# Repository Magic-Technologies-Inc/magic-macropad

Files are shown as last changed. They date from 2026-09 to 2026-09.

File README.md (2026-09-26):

# Magic Macropad

A thin, three-key macropad that plugs straight into your MacBook's side USB-C
port and sits flush along the chassis, plus the menu-bar app that turns each
key into tap, double-tap, triple-tap, and hold actions.

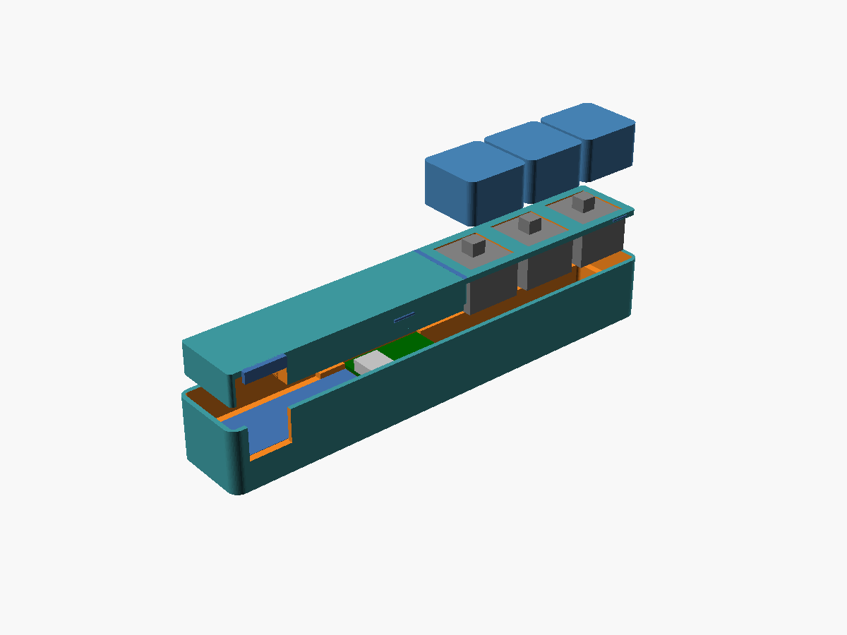
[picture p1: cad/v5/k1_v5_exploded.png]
Exploded view of the side-mount enclosure: tray, drop-in lid, three MX switches, and keycaps


> **Status: early prototype.** The firmware and app work, and the enclosures
> are tuned against real prints. Expect rough edges. The hardware's codename
> is **K1**, and you'll see it in file names and code.

## Features

- **Three keys, twelve bindings.** Each key does something different on tap,
  double-tap, triple-tap, and hold.
- **Per-app profiles.** Bindings follow the frontmost app and fall back to
  your Default profile.
- **Built-in actions:**
  - Open an app, URL, file, or folder
  - Keyboard shortcuts, with a recorder
  - Media: play/pause, previous/next, volume, mute
  - Paste a text snippet
  - System: app switcher (⌘Tab), mic mute, lock screen, display sleep, dark
    mode, region screenshot, Mission Control, keep-awake
  - AI: new Claude or ChatGPT chat, dictation
  - Shell scripts, with a preset library that includes Claude CLI helpers
    like "Improve Writing" for whatever's on the clipboard
- **No drivers.** The device is a vendor-defined USB HID device, so macOS
  needs nothing installed. Gesture timing lives in the app, so you can tune
  it without reflashing.
- **Key-press light.** The board's RGB LED glows red, green, or blue while a
  key is held.

There's also one easter egg. Try pressing all three keys at once.

## How it works

    keys ──► RP2040 firmware ─── USB HID ───► Magic Macropad app
             debounce, down/up events          HIDService → GestureEngine
             8-byte reports + sequence byte      → ActionEngine (per-app profiles)

The firmware only reports debounced key down/up events. It uses a
vendor-defined HID interface (usage page `0xFF60`, 8-byte reports with a
sequence byte). The app does everything else: gesture detection, profiles, and
running actions. The full design is in
[`docs/superpowers/specs/`](docs/superpowers/specs/).

## Build one

You'll need an RP2040-Zero, three MX-style switches and keycaps, some thin
wire, a 3D printer, and a soldering iron. The side-mount version also needs a
90° USB-C adapter and a USB-C coupler; the desk version uses a normal cable.

**[The build guide](docs/build-guide.md)** walks through it step by step:

1. Choose a variant: side-mount or desk
2. Gather parts and tools
3. Print the enclosure
4. Flash the firmware
5. Install the app
6. Wire and test the switches, with a wiring diagram and a self-test
7. Assemble
8. Troubleshooting
9. Changing the enclosure, for other USB parts or printers

Prebuilt firmware is on the
[Releases page](https://github.com/Magic-Technologies-Inc/magic-macropad/releases),
so you only need the firmware toolchain if you change the firmware. No board
yet? You can still install the app (step 5). Its **Test keys** menu simulates
presses.

## Repository layout

- `cad/`: OpenSCAD enclosure, one folder per revision (`v5/` and `desk/v2/`
  are current)
- `firmware/`: Pico SDK and TinyUSB firmware for the RP2040-Zero
- `mac/`: the menu-bar app (SwiftUI). `MagicKeysCore/` holds the unit-tested
  core. The target and package still use the older "Magic Keys" name.
- `docs/build-guide.md`: the step-by-step build guide
- `docs/superpowers/`: design specs and implementation plans. They predate the
  Magic Macropad name, so they still say "K1" and "Magic Keys".

## Contributing

See [CONTRIBUTING.md](CONTRIBUTING.md).

## License

Magic Macropad (hardware designs, firmware, and app) is © 2026 Magic
Technologies Inc., licensed under
[CC BY-NC-SA 4.0](https://creativecommons.org/licenses/by-nc-sa/4.0/). The
full text is in [LICENSE](LICENSE).

In plain English (the license itself is what counts):

- ✅ You can build one, change it, and share your changes. Credit Magic and
  keep the same license.
- ❌ You can't sell devices, kits, printed parts, or the software, modified or
  not.
- **Additional permission:** beyond CC BY-NC-SA 4.0, Magic Technologies Inc.
  lets you use a Magic Macropad you built yourself, along with its firmware
  and app, for your work, including at a for-profit company. This covers use
  only. It doesn't allow selling, renting, or otherwise commercially
  distributing devices, kits, parts, design files, or software.

For commercial licensing, get in touch at [usemagic.io](https://usemagic.io).

Some bundled fonts, a sound, and two small firmware files are third-party and
keep their own licenses; see [THIRD_PARTY_NOTICES.md](THIRD_PARTY_NOTICES.md). The Magic name and logo aren't
licensed at all; see [TRADEMARKS.md](TRADEMARKS.md).

---

Made by [Magic](https://usemagic.io).

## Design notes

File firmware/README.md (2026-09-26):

# Magic Macropad firmware

Pico SDK firmware for the RP2040-Zero (Waveshare design), codename K1. It
enumerates as a vendor HID device and reports debounced key down/up events:
manufacturer "Magic", product "Magic Macropad", VID 0x1209, PID 0x0001, usage
page 0xFF60. There's no gesture logic on the device. The protocol is in
`main/protocol.h`.

PID `0x0001` is the pid.codes shared *test* PID, a placeholder until the
project has its own.

Building a whole pad? Start with the [build guide](../docs/build-guide.md),
which also covers installing the toolchain. Prebuilt `.uf2` files are attached
to the GitHub releases.

## Build

    export PICO_SDK_PATH=~/pico-sdk        # Pico SDK 2.x with the tinyusb submodule
    export PICO_TOOLCHAIN_PATH=/path/to/arm-gnu-toolchain   # Arm GNU Toolchain 14.x (arm-none-eabi)
    cmake -B build -G Ninja -DCMAKE_BUILD_TYPE=Release
    ninja -C build

Produces `build/k1_firmware.uf2`. On macOS, use Arm's official toolchain
download. Homebrew's `arm-none-eabi-gcc` formula ships without newlib and
fails on `nosys.specs`.

## Flash

Hold BOOT while plugging the board in, then drag the UF2 onto the mounted
`RPI-RP2` volume, or run `picotool load -f build/k1_firmware.uf2`.

## Tests

- Host unit tests (no hardware):
  `cc -I main tests/host/test_debounce.c main/debounce.c -o /tmp/test_debounce && /tmp/test_debounce`
  and `cc -I main tests/host/test_keysync.c main/keysync.c -o /tmp/test_keysync && /tmp/test_keysync`
- Hardware-in-loop: `tools/smoke_test.py` (see its docstring)

Key GPIOs are defined in `main/keys.c` (`K1_KEY_GPIOS`): GPIO 12, 11, and 10
for keys 0, 1, and 2 (the app's Key 1–3). They're active-low (key to GND) with
internal pull-ups. Debug logs go out UART0 on GPIO 0/1 at 115200; wiring it is
optional.

While the host isn't listening (bus suspended, not yet mounted), key edges
are dropped rather than replayed later as live presses; when it's back, any
key whose state changed meanwhile is reported once (`main/keysync.c`).

The onboard WS2812 (GPIO 16) shows a dim per-key color while a key is held
(red/green/blue for keys 0/1/2); see `main/led.c`.

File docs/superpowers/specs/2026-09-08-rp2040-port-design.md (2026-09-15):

# K1 Firmware RP2040 Port — Design

**Date:** 2026-09-08
**Status:** Approved (replaces the ESP32-S3 target entirely)

## Decision

K1 firmware moves from the Seeed XIAO ESP32-S3 (ESP-IDF 5.x + `esp_tinyusb`)
to the **RP2040-Zero** (Waveshare design; hiBCTR clones on hand), built with
the **Raspberry Pi Pico SDK** and its bundled TinyUSB. The RP2040 replaces the
ESP32-S3 — there is no dual-target support. K1 never needed WiFi/BLE, the
RP2040 is cheaper, and its native USB + TinyUSB support is first-class.

## What does not change

- **Wire protocol** (`main/protocol.h`): 8-byte vendor HID reports, usage page
  `0xFF60`, VID `0x1209` / PID `0x0001` (dev), `KEY_EVENT` / `INFO` /
  `GET_INFO` messages, sequence byte semantics. Byte-for-byte identical.
- **Mac app (Magic Keys)**: zero changes. It matches on VID/PID/usage page and
  parses the same reports.
- **Debounce** (`main/debounce.c/h`): pure logic, 5 samples @ 1 kHz = 5 ms.
  Carries over untouched, along with its host unit test
  (`tests/host/test_debounce.c`).
- **Smoke test** (`tools/smoke_test.py`): host-side `hidapi` script; VID/PID
  and protocol unchanged, so it runs as-is.
- **Firmware-stays-dumb rule**: only debounced down/up events with a sequence
  byte; all gesture logic remains in the app.

## What changes

### Architecture: FreeRTOS tasks → bare-metal superloop

ESP-IDF forced FreeRTOS (scan task + report task + queue). The Pico SDK is
bare-metal by default and TinyUSB's idiomatic use is a main loop calling
`tud_task()`. The port drops FreeRTOS:

- `main()` loop: `tud_task()` → `k1_keys_poll()` → `k1_usb_flush()`.
- **Key scanning**: `k1_keys_poll()` self-paces to 1 kHz using
  `time_us_64()`; on each 1 ms tick it samples the three GPIOs, runs the
  debouncer, and pushes state changes into a `pico/util/queue` (32 entries,
  drop-oldest-behavior preserved: on a full queue the new event is dropped and
  logged, same as the ESP build).
- **Reporting**: `k1_usb_flush()` mirrors the old report task — answer a
  pending `GET_INFO` first, then drain one key event per call when
  `tud_hid_ready()`. Seq still only advances on successful `tud_hid_report()`.

The loop iterates in microseconds, so 1 kHz sampling jitter is negligible
versus the 5-sample debounce window.

### Files

| File | Change |
|---|---|
| `CMakeLists.txt` | Pico SDK project (`pico_sdk_import.cmake`, `PICO_BOARD=waveshare_rp2040_zero`) |
| `pico_sdk_import.cmake` | New — standard SDK import shim |
| `main/k1_main.c` | `app_main` → `main()` with init + superloop |
| `main/keys.c/h` | ESP GPIO/task/queue → Pico GPIO + polled scan + `pico/util/queue` |
| `main/usb_hid.c/h` | Descriptors/callbacks unchanged; `esp_tinyusb` install → `tusb_init()`; report task → `k1_usb_flush()` |
| `main/tusb_config.h` | New — TinyUSB device config (previously hidden in `esp_tinyusb` + sdkconfig) |
| `sdkconfig*`, `dependencies.lock`, `main/idf_component.yml` | Deleted (ESP-IDF artifacts) |

### Pins (RP2040-Zero)

Keys on **GPIO 10 / 11 / 12** (changed 2026-09-15 for the enclosure wiring;
previously 0/1/2, and 26/27/28 before that), active-low to GND, internal
pull-ups. Defined in one array in `keys.c`. Debug logging via `printf` on
UART0 (GPIO 0/1, 115200), optional to wire.

### Build & flash

- Toolchain: CMake + Ninja + `arm-none-eabi-gcc` + Pico SDK (pinned 2.x with
  TinyUSB submodule).
- `cmake -B build && ninja -C build` → `k1_firmware.uf2`.
- Flash: hold BOOT, plug in, drag the UF2 onto the `RPI-RP2` volume (or
  `picotool load`). No serial flasher, no `idf.py`.

## Error handling

Same posture as the ESP build: best-effort delivery. Queue overflow drops the
newest event with a log line; reports only send when the host is polling; a
failed `tud_hid_report()` does not advance the sequence byte, so the app's gap
detection only fires on real USB loss.

## Testing

1. Host unit test for debounce (unchanged, run in CI fashion locally).
2. Build must produce a UF2.
3. Hardware-in-loop: flash an RP2040-Zero, run `tools/smoke_test.py`
   (enumeration, GET_INFO round-trip, key events with jumper wire).

## Out of scope

- Enclosure CAD update — v2 CAD models the XIAO footprint; the RP2040-Zero is
  ~18×23.5 mm with a different pad layout, so the board pocket needs rework in
  a separate CAD task.
- ~~The WS2812 RGB LED on the RP2040-Zero (GPIO 16)~~ — added 2026-09-08 as a
  key-press indicator: PIO-driven WS2812 shows a dim per-key color while a key
  is held (red/green/blue for keys 0/1/2, highest-index wins), off otherwise.
  Purely local feedback; nothing on the wire.
- OTA/DFU beyond the built-in BOOTSEL UF2 bootloader.

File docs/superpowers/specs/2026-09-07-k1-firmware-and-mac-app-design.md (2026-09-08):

# K1 Firmware & Magic Keys Mac App — Design

**Date:** 2026-09-07
**Status:** Approved

## Product summary

K1 ("Keys v1") is a thin **3-key** macro pad built on an ESP32-S3. It plugs into a
MacBook's side USB-C port and sits flush along the chassis edge. The device is
**app-required**: it emits raw key events over USB and does nothing on its own.
The companion Mac app, **Magic Keys**, detects gestures (tap / double-tap / hold)
and executes user-configured actions, with a Logitech-Options-style configuration
UI.

> Note: `cad/k1_v1.scad` still models 4 keys (`key_count = 4`); the confirmed spec
> is 3 keys. CAD update is out of scope for this spec.

## Repository layout

Single repo (`K1/`) so protocol changes in firmware and app land together:

- `cad/` — enclosure sources and renders
- `firmware/` — ESP-IDF project
- `mac/` — Magic Keys Xcode project
- `docs/` — specs and plans

## Firmware (ESP-IDF + TinyUSB)

- **Stack:** ESP-IDF 5.x with the `esp_tinyusb` component. The ESP32-S3's native
  USB peripheral enumerates as a single **vendor-defined HID** interface, usage
  page `0xFF60` (QMK raw-HID convention), fixed 8-byte reports, full speed.
- **Input:** 3 keys on GPIOs, scanned by a FreeRTOS task with 5 ms debounce.
- **Deliberately dumb:** firmware sends only `down`/`up` events. All gesture
  timing lives in the app so it can be tuned without reflashing.
- **USB IDs (dev):** VID `0x1209` (pid.codes) with a test PID until Magic has its
  own VID.

### Report protocol (8 bytes, little-endian)

Device → host:

| Byte | Field | Values |
|---|---|---|
| 0 | msg | `0x01` KEY_EVENT, `0x02` INFO |
| 1 | key | 0–2 (KEY_EVENT) |
| 2 | state | `0x00` up, `0x01` down (KEY_EVENT) |
| 3 | seq | wrapping counter; app detects dropped reports |
| 4–7  | payload | INFO: fw version major/minor, key count, 0  |

Host → device (output report, 8 bytes): byte 0 `0x10` GET_INFO → device replies
with INFO. This is the extension point for future LED/config messages.

## Magic Keys Mac app

SwiftUI menu-bar app (`MenuBarExtra`), macOS 14+. Four isolated units:

1. **HIDService** — wraps `IOHIDManager`: matches VID/PID, handles
   hotplug/reconnect, parses raw reports into typed `KeyEvent`s, sends GET_INFO
   on connect. The only unit that touches IOKit.
2. **GestureEngine** — pure logic, no I/O. Consumes `KeyEvent`s, emits `tap`,
   `doubleTap`, `hold` per key. Thresholds configurable (defaults: double-tap
   window 300 ms, hold 400 ms). Fully unit-testable with synthetic events.
3. **ActionEngine** — executes the action bound to (key, gesture). V1 actions:
   - Open app
   - Open URL
   - Keyboard shortcut injection (`CGEvent`; requests Accessibility permission
     only when first used)
   - Media control (play/pause, volume up/down, mute)
   - Run shell script
   Actions are a Codable `ActionConfig` enum with an exhaustive switch in
   ActionEngine — adding a later action (e.g. smart-home triggers via the Magic
   FastAPI server) is one new enum case plus one switch arm, and the compiler
   flags every site that must handle it. (Chosen over a `MagicAction` protocol
   because enums get Codable persistence for free.)
4. **ConfigStore** — Codable JSON at
   `~/Library/Application Support/MagicKeys/config.json`, observed by the UI.

### Configuration UI

Logitech-Options-style window: K1 render on the left (placeholder:
`cad/k1_v1_assembled.png`), click a key to select it; right panel shows three
gesture slots (tap / double-tap / hold), each with an action picker and its
parameters. Menu-bar icon reflects connection state. Launch-at-login via
`SMAppService`.

## Error handling

- Disconnect → grayed menu icon, in-flight gesture state reset; IOHIDManager
  auto-resumes on replug.
- Malformed or out-of-sequence reports are logged and dropped.
- Failed actions (script error, missing app) post a user notification; the
  engine never crashes on action failure.

## Testing

- **GestureEngine / ConfigStore:** unit tests with synthetic event streams —
  the bulk of the logic, no hardware needed.
- **HID path:** debug-menu "virtual K1" injects fake reports so the whole app
  runs without hardware.
- **Firmware:** hardware-in-loop smoke test — Python `hidapi` script asserting
  key-event delivery and the GET_INFO round trip.

## Out of scope (v1)

- CAD change from 4 → 3 keys
- LEDs, on-device config storage, OTA/DFU
- Smart-home actions (protocol hook exists via `MagicAction`)
- Windows/Linux hosts

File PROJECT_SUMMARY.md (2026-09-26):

# Magic Macropad (K1) Project Summary

**Last updated:** 2026-09-26

## What it is

Magic Macropad (codename K1, "Keys v1") is a Magic hardware product: a thin
**3-key** macro pad that plugs into a MacBook's side USB-C port and sits flush
along the chassis edge, running toward the front. There's also a desk variant
that takes a normal cable. It's built on an **RP2040** (RP2040-Zero board) and
is **app-required**. The device sends raw key events over USB and does nothing
without the companion **Magic Macropad** Mac app, which detects gestures and
runs the user's configured actions.

## Key decisions

| Decision | Choice |
|---|---|
| Key count | 3 (CAD, firmware, and app) |
| Device model | App-required; no standalone HID-keyboard fallback |
| Transport | Native USB, vendor-defined HID (usage page `0xFF60`), 8-byte reports |
| Firmware stack | Pico SDK 2.x + TinyUSB (was ESP-IDF/ESP32-S3; ported 2026-09-08) |
| Board | RP2040-Zero (Waveshare design, hiBCTR clones); keys on GPIO 12/11/10 |
| Gesture logic | Entirely in the Mac app (tap / double-tap / triple-tap / hold); firmware sends only down/up |
| Mac app | SwiftUI menu-bar app, macOS 15+, `IOHIDManager` |
| Config UI | Logitech Options-style: device render, click a key, assign actions per gesture; per-app profiles |
| Actions | Open app/URL/file, keyboard shortcut, media, paste text, system actions, AI (Claude/ChatGPT/dictation), shell script (with presets) |
| Dev USB IDs | VID `0x1209` (pid.codes) + test PID until Magic has its own VID |
| License | CC BY-NC-SA 4.0 (source-available, non-commercial) plus a permission to use self-built devices at work; Magic name and logo reserved |

## Repository layout

- `cad/`: OpenSCAD enclosure revisions `v0`–`v5` (side-mount) and
  `desk/v1`–`v2`, with STLs, renders, and Bambu Studio projects
- `firmware/`: Pico SDK + TinyUSB vendor-HID firmware
- `mac/`: the Magic Macropad app (XcodeGen, target `MagicKeys`) and the
  `MagicKeysCore` package
- `docs/superpowers/specs/`: design specs (historical names)

## Current status

- ✅ Architecture designed and spec approved:
  [docs/superpowers/specs/2026-09-07-k1-firmware-and-mac-app-design.md](docs/superpowers/specs/2026-09-07-k1-firmware-and-mac-app-design.md)
- ✅ Implementation plans (firmware + Mac app, in docs/superpowers/plans/)
- ✅ Firmware: vendor-HID device with debounced key events + GET_INFO, ported
  to RP2040-Zero / Pico SDK, plus per-key WS2812 press colors
  (spec: docs/superpowers/specs/2026-09-08-rp2040-port-design.md)
- ✅ Magic Macropad app: HID pipeline, gesture engine, action engine, per-app
  profiles, config UI, Test keys menu
- ✅ Hardware bring-up (2026-09-08): flashed to a real RP2040-Zero, enumerates
  as 0x1209:0x0001 (product string then "K1", now "Magic Macropad"), smoke
  test PASS (GET_INFO + all key events, gapless seq). Flash tip: a
  CircuitPython board can be kicked into BOOTSEL from the Mac via a 1200-baud
  touch on its /dev/cu.usbmodem* port
- ✅ Enclosure at 3 keys around the RP2040-Zero; fit tuned empirically against
  prints (v4 was the first confirmed fit; v5 raises the USB corridor to meet
  the port; desk v2 is unprinted)
- ✅ Prepared for public release (2026-09-26): renamed Magic Macropad,
  CC BY-NC-SA 4.0, commercial Advercase font purged from history
- ⬜ End-to-end: keys → Magic Macropad app gestures → actions
- ⬜ Dedicated USB PID (pid.codes needs an open-source license, so likely
  Raspberry Pi's RP2040 PID program)

## Explicitly out of scope for v1

On-device config, OTA/DFU, smart-home actions (would be a new `ActionConfig`
case), non-Mac hosts.

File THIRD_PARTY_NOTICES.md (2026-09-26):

# Third-party notices

Magic Macropad is licensed under [CC BY-NC-SA 4.0](LICENSE). The third-party
material below is **not** covered by that license. Each item keeps its own
license. The Magic name and logo aren't licensed at all; see
[TRADEMARKS.md](TRADEMARKS.md).

## Included in this repository

### Inter (UI text font)

- Files: `mac/MagicKeys/Resources/Inter-{Regular,Medium,SemiBold,Bold}.ttf`
- Copyright 2016 The Inter Project Authors (<https://github.com/rsms/inter>)
- License: SIL Open Font License 1.1. The full text ships next to the fonts in
  [`mac/MagicKeys/Resources/Inter-OFL.txt`](mac/MagicKeys/Resources/Inter-OFL.txt)
  and is bundled into the app.

### Easter-egg sound

- File: `mac/MagicKeys/Resources/fart.mp3`
- Source: Pixabay sound effect #6139 ("wet fart", uploaded by
  freesound_community)
- License: [Pixabay Content License](https://pixabay.com/service/license-summary/).
  It's bundled as an app resource. Don't redistribute it on its own.

### Raspberry Pi code (BSD-3-Clause)

- `firmware/main/ws2812.pio`: the WS2812 driver from
  [pico-examples](https://github.com/raspberrypi/pico-examples), trimmed
- `firmware/pico_sdk_import.cmake`: copied from the
  [Pico SDK](https://github.com/raspberrypi/pico-sdk)

Both are under this license:

```text
Copyright 2020 (c) 2020 Raspberry Pi (Trading) Ltd.

Redistribution and use in source and binary forms, with or without modification, are permitted provided that the
following conditions are met:

1. Redistributions of source code must retain the above copyright notice, this list of conditions and the following
   disclaimer.

2. Redistributions in binary form must reproduce the above copyright notice, this list of conditions and the following
   disclaimer in the documentation and/or other materials provided with the distribution.

3. Neither the name of the copyright holder nor the names of its contributors may be used to endorse or promote products
   derived from this software without specific prior written permission.

THIS SOFTWARE IS PROVIDED BY THE COPYRIGHT HOLDERS AND CONTRIBUTORS "AS IS" AND ANY EXPRESS OR IMPLIED WARRANTIES,
INCLUDING, BUT NOT LIMITED TO, THE IMPLIED WARRANTIES OF MERCHANTABILITY AND FITNESS FOR A PARTICULAR PURPOSE ARE
DISCLAIMED. IN NO EVENT SHALL THE COPYRIGHT HOLDER OR CONTRIBUTORS BE LIABLE FOR ANY DIRECT, INDIRECT, INCIDENTAL,
SPECIAL, EXEMPLARY, OR CONSEQUENTIAL DAMAGES (INCLUDING, BUT NOT LIMITED TO, PROCUREMENT OF SUBSTITUTE GOODS OR
SERVICES; LOSS OF USE, DATA, OR PROFITS; OR BUSINESS INTERRUPTION) HOWEVER CAUSED AND ON ANY THEORY OF LIABILITY,
WHETHER IN CONTRACT, STRICT LIABILITY, OR TORT (INCLUDING NEGLIGENCE OR OTHERWISE) ARISING IN ANY WAY OUT OF THE USE OF
THIS SOFTWARE, EVEN IF ADVISED OF THE POSSIBILITY OF SUCH DAMAGE.
```

## Not included

### Advercase (display font)

Magic's brand display face, © Indieground Design. It's commercially licensed
and can't be redistributed, so it isn't in this repo or its history. The app
falls back to the system font without it. Official builds add licensed copies
locally; the paths are gitignored.

## Fetched at build time (not vendored, apart from the two files above)

- [Raspberry Pi Pico SDK](https://github.com/raspberrypi/pico-sdk): BSD-3-Clause
- [TinyUSB](https://github.com/hathach/tinyusb), pulled in by the Pico SDK: MIT

Firmware binaries you build (`.uf2`) contain code from both. If you distribute
binaries, include their copyright notices.

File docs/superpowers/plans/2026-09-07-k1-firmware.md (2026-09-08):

# K1 Firmware Implementation Plan

> **For agentic workers:** REQUIRED SUB-SKILL: Use superpowers:subagent-driven-development (recommended) or superpowers:executing-plans to implement this plan task-by-task. Steps use checkbox (`- [ ]`) syntax for tracking.

**Goal:** ESP32-S3 firmware that enumerates as a vendor-defined USB HID device and reports debounced key down/up events for the 3 keys, answering GET_INFO requests.

**Architecture:** ESP-IDF 5.x + the `esp_tinyusb` component. A scan task samples 3 GPIOs every 1 ms through a host-testable debounce module and pushes events to a FreeRTOS queue; a USB task drains the queue into 8-byte HID input reports. Host→device output reports handle GET_INFO. No gesture logic on-device (see `CLAUDE.md`).

**Tech Stack:** ESP-IDF 5.x, TinyUSB via `espressif/esp_tinyusb`, FreeRTOS, plain `cc` for host unit tests, Python `hidapi` for the hardware-in-loop smoke test.

**Prerequisite:** ESP-IDF installed and exported (`. $IDF_PATH/export.sh` or `idf.py --version` works). All `idf.py` commands run from `firmware/`.

**Protocol (from spec — single source of truth is `main/protocol.h` once created):**
8-byte reports. Device→host: byte0 msg (`0x01` KEY_EVENT, `0x02` INFO), byte1 key (0–2), byte2 state (0 up / 1 down), byte3 wrapping seq, bytes4–7 payload (INFO: fw major, fw minor, key count, 0). Host→device: byte0 `0x10` GET_INFO. USB IDs: VID `0x1209`, PID `0x0001` (pid.codes test PID). HID usage page `0xFF60`, usage `0x61`.

---

### Task 1: ESP-IDF project scaffold

**Files:**
- Create: `firmware/CMakeLists.txt`
- Create: `firmware/sdkconfig.defaults`
- Create: `firmware/main/CMakeLists.txt`
- Create: `firmware/main/idf_component.yml`
- Create: `firmware/main/k1_main.c`

- [ ] **Step 1: Write the project files**

`firmware/CMakeLists.txt`:

```cmake
cmake_minimum_required(VERSION 3.16)
include($ENV{IDF_PATH}/tools/cmake/project.cmake)
project(k1_firmware)
```

`firmware/sdkconfig.defaults`:

```
CONFIG_IDF_TARGET="esp32s3"
CONFIG_TINYUSB_HID_COUNT=1
```

`firmware/main/CMakeLists.txt`:

```cmake
idf_component_register(
    SRCS "k1_main.c"
    INCLUDE_DIRS "."
)
```

`firmware/main/idf_component.yml`:

```yaml
dependencies:
  espressif/esp_tinyusb: "^1"
  idf: ">=5.0"
```

`firmware/main/k1_main.c`:

```c
#include "esp_log.h"

static const char *TAG = "k1";

void app_main(void)
{
    ESP_LOGI(TAG, "K1 firmware boot");
}
```

- [ ] **Step 2: Verify it builds**

Run: `cd firmware && idf.py set-target esp32s3 && idf.py build`
Expected: `Project build complete.` (first run downloads `esp_tinyusb` into `managed_components/`).

- [ ] **Step 3: Commit**

```bash
git add firmware/CMakeLists.txt firmware/sdkconfig.defaults firmware/main/
git commit -m "firmware: ESP-IDF project scaffold for ESP32-S3"
```

---

### Task 2: Protocol header

**Files:**
- Create: `firmware/main/protocol.h`

- [ ] **Step 1: Write the header**

```c
// protocol.h — K1 <-> Magic Keys wire protocol. 8-byte HID reports.
// This file is the single source of truth; the Mac app's Protocol.swift mirrors it.
#pragma once
#include <stdint.h>

#define K1_KEY_COUNT        3
#define K1_REPORT_SIZE      8

#define K1_USB_VID          0x1209  // pid.codes (dev)
#define K1_USB_PID          0x0001  // pid.codes test PID (dev)
#define K1_HID_USAGE_PAGE   0xFF60
#define K1_HID_USAGE        0x61

#define K1_FW_VERSION_MAJOR 0
#define K1_FW_VERSION_MINOR 1

// Device -> host, byte 0
#define K1_MSG_KEY_EVENT    0x01
#define K1_MSG_INFO         0x02
// Host -> device, byte 0
#define K1_MSG_GET_INFO     0x10

// KEY_EVENT byte 2
#define K1_KEY_UP           0x00
#define K1_KEY_DOWN         0x01

typedef struct {
    uint8_t key;    // 0..K1_KEY_COUNT-1
    uint8_t state;  // K1_KEY_UP / K1_KEY_DOWN
} k1_key_event_t;
```

- [ ] **Step 2: Verify it still builds**

Run: `cd firmware && idf.py build`
Expected: `Project build complete.`

- [ ] **Step 3: Commit**

```bash
git add firmware/main/protocol.h
git commit -m "firmware: protocol constants for 8-byte HID reports"
```

---

### Task 3: Debounce module (host-tested, TDD)

The debounce logic is pure C with no ESP-IDF includes so it compiles on the Mac with `cc`.
Contract: sample raw key level every 1 ms; a state change is reported only after
`K1_DEBOUNCE_SAMPLES` (5) consecutive identical samples that differ from the stable state.

**Files:**
- Create: `firmware/main/debounce.h`
- Create: `firmware/main/debounce.c`
- Create: `firmware/tests/host/test_debounce.c`

- [ ] **Step 1: Write the header and the failing test**

`firmware/main/debounce.h`:

```c
#pragma once
#include <stdbool.h>
#include <stdint.h>

#define K1_DEBOUNCE_SAMPLES 5  // at 1 ms/sample => 5 ms debounce

typedef struct {
    bool stable;     // debounced state (true = pressed)
    bool candidate;  // last raw sample
    uint8_t count;   // consecutive samples matching candidate
} k1_debounce_t;

void k1_debounce_init(k1_debounce_t *d, bool initial);
// Feed one raw sample. Returns true iff the stable state just changed
// (read the new state from d->stable).
bool k1_debounce_update(k1_debounce_t *d, bool raw);
```

`firmware/tests/host/test_debounce.c`:

```c
#include <assert.h>
#include <stdio.h>
#include "debounce.h"

static void test_stays_idle_without_input(void) {
    k1_debounce_t d;
    k1_debounce_init(&d, false);
    for (int i = 0; i < 100; i++) assert(!k1_debounce_update(&d, false));
    assert(d.stable == false);
}

static void test_clean_press_fires_after_5_samples(void) {
    k1_debounce_t d;
    k1_debounce_init(&d, false);
    for (int i = 0; i < K1_DEBOUNCE_SAMPLES - 1; i++)
        assert(!k1_debounce_update(&d, true));
    assert(k1_debounce_update(&d, true));   // 5th sample flips it
    assert(d.stable == true);
    assert(!k1_debounce_update(&d, true));  // no repeat events while held
}

static void test_bounce_is_ignored(void) {
    k1_debounce_t d;
    k1_debounce_init(&d, false);
    // 3 pressed samples, then a bounce back to released, resets the counter
    assert(!k1_debounce_update(&d, true));
    assert(!k1_debounce_update(&d, true));
    assert(!k1_debounce_update(&d, true));
    assert(!k1_debounce_update(&d, false));
    assert(d.stable == false);
    // now a clean press still needs 5 consecutive samples
    for (int i = 0; i < K1_DEBOUNCE_SAMPLES - 1; i++)
        assert(!k1_debounce_update(&d, true));
    assert(k1_debounce_update(&d, true));
}

static void test_release_debounces_too(void) {
    k1_debounce_t d;
    k1_debounce_init(&d, true);
    for (int i = 0; i < K1_DEBOUNCE_SAMPLES - 1; i++)
        assert(!k1_debounce_update(&d, false));
    assert(k1_debounce_update(&d, false));
    assert(d.stable == false);
}

int main(void) {
    test_stays_idle_without_input();
    test_clean_press_fires_after_5_samples();
    test_bounce_is_ignored();
    test_release_debounces_too();
    printf("debounce: all tests passed\n");
    return 0;
}
```

- [ ] **Step 2: Run the test to verify it fails**

Run: `cd firmware && cc -I main tests/host/test_debounce.c main/debounce.c -o /tmp/test_debounce && /tmp/test_debounce`
Expected: FAIL — `main/debounce.c: No such file or directory` (not written yet).

- [ ] **Step 3: Write the implementation**

`firmware/main/debounce.c`:

```c
#include "debounce.h"

void k1_debounce_init(k1_debounce_t *d, bool initial)
{
    d->stable = initial;
    d->candidate = initial;
    d->count = 0;
}

bool k1_debounce_update(k1_debounce_t *d, bool raw)
{
    if (raw != d->candidate) {
        d->candidate = raw;
        d->count = 1;
        return false;
    }
    if (d->candidate == d->stable) {
        d->count = 0;
        return false;
    }
    if (++d->count >= K1_DEBOUNCE_SAMPLES) {
        d->stable = d->candidate;
        d->count = 0;
        return true;
    }
    return false;
}
```

- [ ] **Step 4: Run the test to verify it passes**

Run: `cd firmware && cc -I main tests/host/test_debounce.c main/debounce.c -o /tmp/test_debounce && /tmp/test_debounce`
Expected: `debounce: all tests passed`

- [ ] **Step 5: Add debounce.c to the ESP build and verify**

In `firmware/main/CMakeLists.txt`, change the SRCS line:

```cmake
idf_component_register(
    SRCS "k1_main.c" "debounce.c"
    INCLUDE_DIRS "."
)
```

Run: `cd firmware && idf.py build`
Expected: `Project build complete.`

- [ ] **Step 6: Commit**

```bash
git add firmware/main/debounce.h firmware/main/debounce.c firmware/tests/host/test_debounce.c firmware/main/CMakeLists.txt
git commit -m "firmware: host-tested debounce module (5 ms, 1 ms sampling)"
```

---

### Task 4: Key scan task

**Files:**
- Create: `firmware/main/keys.h`
- Create: `firmware/main/keys.c`
- Modify: `firmware/main/CMakeLists.txt`
- Modify: `firmware/main/k1_main.c`

Keys are active-low on GPIO 1, 2, 3 with internal pull-ups (breadboard wiring as of
2026-09-07; `K1_KEY_GPIOS` in keys.c is the only place pins appear). Wire each key
between its GPIO and GND. Note: GPIO 3 is an ESP32-S3 strapping pin (JTAG source
selection) — harmless with default eFuses, but avoid holding key 3 down during reset.

- [ ] **Step 1: Write keys.h**

```c
#pragma once
#include "freertos/FreeRTOS.h"
#include "freertos/queue.h"

// Starts the 1 kHz scan task. Debounced key events are posted to the
// returned queue as k1_key_event_t (see protocol.h).
QueueHandle_t k1_keys_start(void);
```

- [ ] **Step 2: Write keys.c**

```c
#include "keys.h"
#include "protocol.h"
#include "debounce.h"
#include "driver/gpio.h"
#include "esp_log.h"
#include "freertos/task.h"

static const char *TAG = "k1_keys";

// Active-low keys, wired key -> GND on the breadboard.
static const gpio_num_t K1_KEY_GPIOS[K1_KEY_COUNT] = {
    GPIO_NUM_1, GPIO_NUM_2, GPIO_NUM_3,
};

static QueueHandle_t s_event_queue;

static void scan_task(void *arg)
{
    k1_debounce_t db[K1_KEY_COUNT];
    for (int i = 0; i < K1_KEY_COUNT; i++)
        k1_debounce_init(&db[i], false);

    TickType_t last_wake = xTaskGetTickCount();
    for (;;) {
        for (int i = 0; i < K1_KEY_COUNT; i++) {
            bool pressed = gpio_get_level(K1_KEY_GPIOS[i]) == 0; // active low
            if (k1_debounce_update(&db[i], pressed)) {
                k1_key_event_t ev = {
                    .key = (uint8_t)i,
                    .state = db[i].stable ? K1_KEY_DOWN : K1_KEY_UP,
                };
                if (xQueueSend(s_event_queue, &ev, 0) != pdTRUE)
                    ESP_LOGW(TAG, "event queue full, dropped key %d", i);
            }
        }
        vTaskDelayUntil(&last_wake, pdMS_TO_TICKS(1));
    }
}

QueueHandle_t k1_keys_start(void)
{
    gpio_config_t cfg = {
        .mode = GPIO_MODE_INPUT,
        .pull_up_en = GPIO_PULLUP_ENABLE,
    };
    for (int i = 0; i < K1_KEY_COUNT; i++) {
        cfg.pin_bit_mask = 1ULL << K1_KEY_GPIOS[i];
        ESP_ERROR_CHECK(gpio_config(&cfg));
    }
    s_event_queue = xQueueCreate(32, sizeof(k1_key_event_t));
    configASSERT(s_event_queue);
    xTaskCreate(scan_task, "k1_scan", 3072, NULL, 10, NULL);
    return s_event_queue;
}
```

- [ ] **Step 3: Wire into main and the build**

`firmware/main/CMakeLists.txt` SRCS becomes:

```cmake
idf_component_register(
    SRCS "k1_main.c" "debounce.c" "keys.c"
    INCLUDE_DIRS "."
)
```

`firmware/main/k1_main.c` becomes:

```c
#include "esp_log.h"
#include "keys.h"
#include "protocol.h"
#include "freertos/FreeRTOS.h"
#include "freertos/queue.h"

static const char *TAG = "k1";

void app_main(void)
{
    ESP_LOGI(TAG, "K1 firmware boot, fw %d.%d",
             K1_FW_VERSION_MAJOR, K1_FW_VERSION_MINOR);
    QueueHandle_t q = k1_keys_start();

    // Temporary: log events until USB lands (replaced in Task 5).
    k1_key_event_t ev;
    for (;;) {
        if (xQueueReceive(q, &ev, portMAX_DELAY) == pdTRUE)
            ESP_LOGI(TAG, "key %d %s", ev.key,
                     ev.state == K1_KEY_DOWN ? "down" : "up");
    }
}
```

- [ ] **Step 4: Build (and flash if hardware is connected)**

Run: `cd firmware && idf.py build`
Expected: `Project build complete.`

If a board is connected: `idf.py flash monitor` — pressing keys (or grounding GPIO 1/2/3) logs `key N down` / `key N up`, one pair per press, no bounce storms. Ctrl+] exits monitor.

- [ ] **Step 5: Commit**

```bash
git add firmware/main/keys.h firmware/main/keys.c firmware/main/k1_main.c firmware/main/CMakeLists.txt
git commit -m "firmware: 1 kHz debounced key scan task on GPIO 4/5/6"
```

---

### Task 5: USB vendor HID device

**Files:**
- Create: `firmware/main/usb_hid.h`
- Create: `firmware/main/usb_hid.c`
- Modify: `firmware/main/CMakeLists.txt`
- Modify: `firmware/main/k1_main.c`

- [ ] **Step 1: Write usb_hid.h**

```c
#pragma once
#include "freertos/FreeRTOS.h"
#include "freertos/queue.h"

// Installs TinyUSB and starts the report task, which drains key events
// from `key_queue` into HID input reports (see protocol.h).
void k1_usb_start(QueueHandle_t key_queue);
```

- [ ] **Step 2: Write usb_hid.c**

```c
#include "usb_hid.h"
#include "protocol.h"
#include "esp_log.h"
#include "freertos/task.h"
#include "tinyusb.h"
#include "class/hid/hid_device.h"
#include <string.h>

static const char *TAG = "k1_usb";

// ---- Descriptors -----------------------------------------------------------

// Vendor-defined raw HID: 8-byte input + 8-byte output report, no report ID.
static const uint8_t k1_report_descriptor[] = {
    0x06, (K1_HID_USAGE_PAGE & 0xFF), (K1_HID_USAGE_PAGE >> 8), // Usage Page (0xFF60)
    0x09, K1_HID_USAGE,             // Usage (0x61)
    0xA1, 0x01,                     // Collection (Application)
    0x09, 0x62,                     //   Usage (vendor, input)
    0x15, 0x00,                     //   Logical Min 0
    0x26, 0xFF, 0x00,               //   Logical Max 255
    0x75, 0x08,                     //   Report Size 8 bits
    0x95, K1_REPORT_SIZE,           //   Report Count 8
    0x81, 0x02,                     //   Input (Data,Var,Abs)
    0x09, 0x63,                     //   Usage (vendor, output)
    0x15, 0x00,
    0x26, 0xFF, 0x00,
    0x75, 0x08,
    0x95, K1_REPORT_SIZE,
    0x91, 0x02,                     //   Output (Data,Var,Abs)
    0xC0                            // End Collection
};

static const tusb_desc_device_t k1_device_descriptor = {
    .bLength = sizeof(tusb_desc_device_t),
    .bDescriptorType = TUSB_DESC_DEVICE,
    .bcdUSB = 0x0200,
    .bDeviceClass = 0x00,
    .bDeviceSubClass = 0x00,
    .bDeviceProtocol = 0x00,
    .bMaxPacketSize0 = CFG_TUD_ENDPOINT0_SIZE,
    .idVendor = K1_USB_VID,
    .idProduct = K1_USB_PID,
    .bcdDevice = 0x0001,
    .iManufacturer = 1,
    .iProduct = 2,
    .iSerialNumber = 3,
    .bNumConfigurations = 1,
};

static const char *k1_string_descriptor[] = {
    (const char[]){0x09, 0x04},  // 0: English (US)
    "Magic",                     // 1: manufacturer
    "K1",                        // 2: product
    "K1-DEV-0001",               // 3: serial
};

enum { ITF_NUM_HID = 0, ITF_NUM_TOTAL };
#define K1_CONFIG_DESC_LEN (TUD_CONFIG_DESC_LEN + TUD_HID_INOUT_DESC_LEN)

static const uint8_t k1_configuration_descriptor[] = {
    TUD_CONFIG_DESCRIPTOR(1, ITF_NUM_TOTAL, 0, K1_CONFIG_DESC_LEN,
                          TUSB_DESC_CONFIG_ATT_REMOTE_WAKEUP, 100),
    TUD_HID_INOUT_DESCRIPTOR(ITF_NUM_HID, 0, HID_ITF_PROTOCOL_NONE,
                             sizeof(k1_report_descriptor),
                             0x01 /* EP OUT */, 0x81 /* EP IN */,
                             K1_REPORT_SIZE, 5 /* poll ms */),
};

// ---- TinyUSB HID callbacks -------------------------------------------------

static uint8_t s_seq;
static volatile bool s_info_requested;

uint8_t const *tud_hid_descriptor_report_cb(uint8_t instance)
{
    (void)instance;
    return k1_report_descriptor;
}

uint16_t tud_hid_get_report_cb(uint8_t instance, uint8_t report_id,
                               hid_report_type_t report_type,
                               uint8_t *buffer, uint16_t reqlen)
{
    (void)instance; (void)report_id; (void)report_type; (void)buffer; (void)reqlen;
    return 0;
}

void tud_hid_set_report_cb(uint8_t instance, uint8_t report_id,
                           hid_report_type_t report_type,
                           uint8_t const *buffer, uint16_t bufsize)
{
    (void)instance; (void)report_id; (void)report_type;
    if (bufsize >= 1 && buffer[0] == K1_MSG_GET_INFO)
        s_info_requested = true;  // answered from the report task, not this ISR-ish context
}

// ---- Report task -----------------------------------------------------------

static void send_report(uint8_t msg, uint8_t b1, uint8_t b2,
                        uint8_t p0, uint8_t p1, uint8_t p2, uint8_t p3)
{
    uint8_t report[K1_REPORT_SIZE] = {msg, b1, b2, s_seq++, p0, p1, p2, p3};
    if (!tud_hid_report(0, report, sizeof(report)))
        ESP_LOGW(TAG, "report dropped (host not ready)");
}

static void report_task(void *arg)
{
    QueueHandle_t key_queue = (QueueHandle_t)arg;
    k1_key_event_t ev;
    for (;;) {
        if (s_info_requested && tud_hid_ready()) {
            s_info_requested = false;
            send_report(K1_MSG_INFO, 0, 0,
                        K1_FW_VERSION_MAJOR, K1_FW_VERSION_MINOR,
                        K1_KEY_COUNT, 0);
        }
        if (xQueueReceive(key_queue, &ev, pdMS_TO_TICKS(10)) == pdTRUE) {
            while (!tud_hid_ready())
                vTaskDelay(pdMS_TO_TICKS(1));
            send_report(K1_MSG_KEY_EVENT, ev.key, ev.state, 0, 0, 0, 0);
        }
    }
}

void k1_usb_start(QueueHandle_t key_queue)
{
    const tinyusb_config_t tusb_cfg = {
        .device_descriptor = &k1_device_descriptor,
        .string_descriptor = k1_string_descriptor,
        .string_descriptor_count =
            sizeof(k1_string_descriptor) / sizeof(k1_string_descriptor[0]),
        .external_phy = false,
        .configuration_descriptor = k1_configuration_descriptor,
    };
    ESP_ERROR_CHECK(tinyusb_driver_install(&tusb_cfg));
    xTaskCreate(report_task, "k1_usb_report", 4096, key_queue, 9, NULL);
    ESP_LOGI(TAG, "USB HID started (VID %04x PID %04x)", K1_USB_VID, K1_USB_PID);
}
```

- [ ] **Step 3: Wire into main and the build**

`firmware/main/CMakeLists.txt` SRCS becomes:

```cmake
idf_component_register(
    SRCS "k1_main.c" "debounce.c" "keys.c" "usb_hid.c"
    INCLUDE_DIRS "."
)
```

`firmware/main/k1_main.c` becomes (log loop replaced by USB):

```c
#include "esp_log.h"
#include "keys.h"
#include "usb_hid.h"
#include "protocol.h"

static const char *TAG = "k1";

void app_main(void)
{
    ESP_LOGI(TAG, "K1 firmware boot, fw %d.%d",
             K1_FW_VERSION_MAJOR, K1_FW_VERSION_MINOR);
    k1_usb_start(k1_keys_start());
}
```

- [ ] **Step 4: Build**

Run: `cd firmware && idf.py build`
Expected: `Project build complete.` If `tinyusb.h` is not found, `managed_components/` wasn't resolved — run `idf.py reconfigure` first. If the esp_tinyusb API differs (e.g. no `string_descriptor_count` field on the installed version), match the struct fields to `managed_components/espressif__esp_tinyusb/include/tinyusb.h` rather than fighting the pin — the descriptor content stays the same.

- [ ] **Step 5: Flash and verify enumeration on the Mac**

Run: `cd firmware && idf.py flash`

Then on the Mac: `system_profiler SPUSBDataType | grep -A6 K1`
Expected: a `K1` device with `Vendor ID: 0x1209`, `Product ID: 0x0001`.

- [ ] **Step 6: Commit**

```bash
git add firmware/main/usb_hid.h firmware/main/usb_hid.c firmware/main/k1_main.c firmware/main/CMakeLists.txt
git commit -m "firmware: vendor HID device, key events + GET_INFO over 8-byte reports"
```

---

### Task 6: Hardware-in-loop smoke test

**Files:**
- Create: `firmware/tools/smoke_test.py`
- Create: `firmware/tools/requirements.txt`

- [ ] **Step 1: Write the tool files**

`firmware/tools/requirements.txt`:

```
hidapi>=0.14
```

`firmware/tools/smoke_test.py`:

```python
#!/usr/bin/env python3
"""K1 hardware-in-loop smoke test.

Verifies: device opens, GET_INFO round-trips, and key events arrive
with correct shape and sequence numbers. Run with the K1 plugged in:

    python3 -m venv .venv && .venv/bin/pip install -r requirements.txt
    .venv/bin/python smoke_test.py
"""
import sys
import time

import hid

VID, PID = 0x1209, 0x0001
MSG_KEY_EVENT, MSG_INFO, MSG_GET_INFO = 0x01, 0x02, 0x10
KEY_COUNT = 3

def fail(msg):
    print(f"FAIL: {msg}")
    sys.exit(1)

def main():
    try:
        dev = hid.device()
        dev.open(VID, PID)
    except OSError:
        fail(f"no HID device {VID:04x}:{PID:04x} — is the K1 plugged in?")
    dev.set_nonblocking(False)
    print(f"opened {dev.get_manufacturer_string()} {dev.get_product_string()}")

    # GET_INFO round trip. First byte 0x00 is the report ID (none).
    dev.write([0x00, MSG_GET_INFO] + [0] * 7)
    report = dev.read(8, timeout_ms=1000)
    if not report:
        fail("no INFO reply within 1 s")
    if report[0] != MSG_INFO:
        fail(f"expected INFO (0x02), got 0x{report[0]:02x}")
    major, minor, keys = report[4], report[5], report[6]
    if keys != KEY_COUNT:
        fail(f"device reports {keys} keys, expected {KEY_COUNT}")
    print(f"INFO ok: fw {major}.{minor}, {keys} keys")

    # Key events: one press+release per key, in order.
    print("press and release each key once, left to right (30 s timeout)...")
    deadline = time.time() + 30
    seen, last_seq = [], None
    while len(seen) < KEY_COUNT * 2 and time.time() < deadline:
        report = dev.read(8, timeout_ms=500)
        if not report:
            continue
        if report[0] != MSG_KEY_EVENT:
            continue
        key, state, seq = report[1], report[2], report[3]
        if key >= KEY_COUNT or state not in (0, 1):
            fail(f"malformed report: {report}")
        if last_seq is not None and seq != (last_seq + 1) % 256:
            fail(f"sequence gap: {last_seq} -> {seq}")
        last_seq = seq
        seen.append((key, state))
        print(f"  key {key} {'down' if state else 'up'} (seq {seq})")
    if len(seen) < KEY_COUNT * 2:
        fail(f"timed out; saw {len(seen)}/{KEY_COUNT * 2} events")

    print("PASS: smoke test complete")

if __name__ == "__main__":
    main()
```

- [ ] **Step 2: Run it against hardware**

Run (from `firmware/tools/`):

```bash
python3 -m venv .venv && .venv/bin/pip install -r requirements.txt && .venv/bin/python smoke_test.py
```

Expected: `INFO ok: fw 0.1, 3 keys`, six key-event lines while pressing, then `PASS: smoke test complete`. (Skip gracefully if no hardware is attached — the script exits with the "is the K1 plugged in?" failure.)

- [ ] **Step 3: Add `.venv` to gitignore and commit**

Append to `.gitignore`:

```
firmware/tools/.venv/
```

```bash
git add firmware/tools/smoke_test.py firmware/tools/requirements.txt .gitignore
git commit -m "firmware: hidapi hardware-in-loop smoke test"
```

---

### Task 7: Documentation touch-up

**Files:**
- Modify: `firmware/README.md`
- Modify: `PROJECT_SUMMARY.md`

- [ ] **Step 1: Replace firmware/README.md**

```markdown
# K1 Firmware

ESP-IDF 5.x firmware for the ESP32-S3. Enumerates as a vendor HID device
(VID 0x1209, PID 0x0001, usage page 0xFF60) and reports debounced key
down/up events. Protocol: `main/protocol.h`. No gesture logic on-device.

## Build & flash

    idf.py set-target esp32s3   # first time only
    idf.py build
    idf.py flash monitor

## Tests

- Host unit tests (no hardware):
  `cc -I main tests/host/test_debounce.c main/debounce.c -o /tmp/test_debounce && /tmp/test_debounce`
- Hardware-in-loop: `tools/smoke_test.py` (see its docstring)

Key GPIOs are defined in `main/keys.c` (`K1_KEY_GPIOS`) — GPIO 1/2/3, active-low
(key to GND), internal pull-ups.
```

- [ ] **Step 2: Update PROJECT_SUMMARY.md status**

In the Current status list, change the firmware lines to:

```markdown
- ✅ Implementation plan (firmware + Mac app, in `docs/superpowers/plans/`)
- ✅ Firmware: vendor-HID device with debounced key events + GET_INFO
- ✅ Hardware-in-loop smoke test (Python `hidapi`)
```

- [ ] **Step 3: Commit**

```bash
git add firmware/README.md PROJECT_SUMMARY.md
git commit -m "docs: firmware build/test instructions, status update"
```

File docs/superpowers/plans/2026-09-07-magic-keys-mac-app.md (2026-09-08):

# Magic Keys Mac App Implementation Plan

> **For agentic workers:** REQUIRED SUB-SKILL: Use superpowers:subagent-driven-development (recommended) or superpowers:executing-plans to implement this plan task-by-task. Steps use checkbox (`- [ ]`) syntax for tracking.

**Goal:** SwiftUI menu-bar app that receives K1 key events over vendor HID, detects tap / double-tap / hold gestures, and runs user-configured actions, with a Logitech-style per-key config window.

**Architecture:** All pure logic (protocol parsing, gesture engine, config models, config store) lives in a SwiftPM package `MagicKeysCore`, unit-tested with `swift test` — no Xcode project needed for TDD. The app target (generated by XcodeGen) adds the I/O shells: `HIDService` (IOHIDManager, the only unit touching IOKit), `GesturePipeline` (timers), `ActionEngine` (AppKit/CGEvent execution), and the SwiftUI UI. A DEBUG-only "virtual K1" menu injects fake key events so the whole app runs without hardware.

**Tech Stack:** Swift 5.9+, SwiftUI `MenuBarExtra`, macOS 14+, IOKit.hid, XcodeGen, XCTest.

**Prerequisites:** Xcode 15+ installed; `brew install xcodegen`. All commands run from `mac/` unless noted.

**Protocol (mirrors `firmware/main/protocol.h`):** 8-byte reports; device→host byte0 `0x01` KEY_EVENT (byte1 key 0–2, byte2 state 0 up/1 down, byte3 seq) or `0x02` INFO (bytes4–6 = fw major, fw minor, key count); host→device byte0 `0x10` GET_INFO. VID `0x1209`, PID `0x0001`.

---

### Task 1: MagicKeysCore package scaffold

**Files:**
- Create: `mac/MagicKeysCore/Package.swift`
- Create: `mac/MagicKeysCore/Sources/MagicKeysCore/Protocol.swift` (stub)
- Create: `mac/MagicKeysCore/Tests/MagicKeysCoreTests/ProtocolTests.swift` (stub)

- [ ] **Step 1: Write the package manifest and stubs**

`mac/MagicKeysCore/Package.swift`:

```swift
// swift-tools-version: 5.9
import PackageDescription

let package = Package(
    name: "MagicKeysCore",
    platforms: [.macOS(.v14)],
    products: [
        .library(name: "MagicKeysCore", targets: ["MagicKeysCore"]),
    ],
    targets: [
        .target(name: "MagicKeysCore"),
        .testTarget(name: "MagicKeysCoreTests", dependencies: ["MagicKeysCore"]),
    ]
)
```

`mac/MagicKeysCore/Sources/MagicKeysCore/Protocol.swift`:

```swift
public enum K1Protocol {}
```

`mac/MagicKeysCore/Tests/MagicKeysCoreTests/ProtocolTests.swift`:

```swift
import XCTest
@testable import MagicKeysCore

final class ProtocolTests: XCTestCase {}
```

- [ ] **Step 2: Verify the package builds and tests run**

Run: `cd mac/MagicKeysCore && swift test`
Expected: `Executed 0 tests, with 0 failures`.

- [ ] **Step 3: Commit**

```bash
git add mac/MagicKeysCore
git commit -m "mac: MagicKeysCore SwiftPM package scaffold"
```

---

### Task 2: Protocol parsing (TDD)

**Files:**
- Modify: `mac/MagicKeysCore/Sources/MagicKeysCore/Protocol.swift`
- Modify: `mac/MagicKeysCore/Tests/MagicKeysCoreTests/ProtocolTests.swift`

- [ ] **Step 1: Write the failing tests**

Replace `ProtocolTests.swift`:

```swift
import XCTest
@testable import MagicKeysCore

final class ProtocolTests: XCTestCase {
    func testParsesKeyDownEvent() {
        let msg = K1Protocol.parse([0x01, 2, 1, 42, 0, 0, 0, 0])
        XCTAssertEqual(msg, .keyEvent(KeyEvent(key: 2, isDown: true, seq: 42)))
    }

    func testParsesKeyUpEvent() {
        let msg = K1Protocol.parse([0x01, 0, 0, 255, 0, 0, 0, 0])
        XCTAssertEqual(msg, .keyEvent(KeyEvent(key: 0, isDown: false, seq: 255)))
    }

    func testParsesInfo() {
        let msg = K1Protocol.parse([0x02, 0, 0, 7, 0, 1, 3, 0])
        XCTAssertEqual(msg, .info(DeviceInfo(firmwareMajor: 0, firmwareMinor: 1, keyCount: 3)))
    }

    func testRejectsWrongLength() {
        XCTAssertNil(K1Protocol.parse([0x01, 0, 1]))
    }

    func testRejectsUnknownMessage() {
        XCTAssertNil(K1Protocol.parse([0x77, 0, 0, 0, 0, 0, 0, 0]))
    }

    func testRejectsOutOfRangeKey() {
        XCTAssertNil(K1Protocol.parse([0x01, 3, 1, 0, 0, 0, 0, 0]))
    }

    func testRejectsInvalidState() {
        XCTAssertNil(K1Protocol.parse([0x01, 1, 2, 0, 0, 0, 0, 0]))
    }

    func testGetInfoReportShape() {
        XCTAssertEqual(K1Protocol.getInfoReport, [0x10, 0, 0, 0, 0, 0, 0, 0])
    }
}
```

- [ ] **Step 2: Run tests to verify they fail**

Run: `cd mac/MagicKeysCore && swift test`
Expected: compile errors — `KeyEvent`, `DeviceInfo`, `parse` don't exist yet.

- [ ] **Step 3: Write the implementation**

Replace `Protocol.swift`:

```swift
import Foundation

public struct KeyEvent: Equatable, Sendable {
    public let key: Int
    public let isDown: Bool
    public let seq: UInt8

    public init(key: Int, isDown: Bool, seq: UInt8) {
        self.key = key
        self.isDown = isDown
        self.seq = seq
    }
}

public struct DeviceInfo: Equatable, Sendable {
    public let firmwareMajor: Int
    public let firmwareMinor: Int
    public let keyCount: Int

    public init(firmwareMajor: Int, firmwareMinor: Int, keyCount: Int) {
        self.firmwareMajor = firmwareMajor
        self.firmwareMinor = firmwareMinor
        self.keyCount = keyCount
    }
}

public enum K1Message: Equatable, Sendable {
    case keyEvent(KeyEvent)
    case info(DeviceInfo)
}

/// Mirrors firmware/main/protocol.h — keep in lockstep.
public enum K1Protocol {
    public static let vendorID = 0x1209
    public static let productID = 0x0001
    public static let usagePage = 0xFF60
    public static let reportSize = 8
    public static let keyCount = 3

    static let msgKeyEvent: UInt8 = 0x01
    static let msgInfo: UInt8 = 0x02
    static let msgGetInfo: UInt8 = 0x10

    public static var getInfoReport: [UInt8] {
        [msgGetInfo, 0, 0, 0, 0, 0, 0, 0]
    }

    public static func parse(_ report: [UInt8]) -> K1Message? {
        guard report.count == reportSize else { return nil }
        switch report[0] {
        case msgKeyEvent:
            let key = Int(report[1])
            guard key < keyCount, report[2] <= 1 else { return nil }
            return .keyEvent(KeyEvent(key: key, isDown: report[2] == 1, seq: report[3]))
        case msgInfo:
            return .info(DeviceInfo(firmwareMajor: Int(report[4]),
                                    firmwareMinor: Int(report[5]),
                                    keyCount: Int(report[6])))
        default:
            return nil
        }
    }
}
```

- [ ] **Step 4: Run tests to verify they pass**

Run: `cd mac/MagicKeysCore && swift test`
Expected: `Executed 8 tests, with 0 failures`.

- [ ] **Step 5: Commit**

```bash
git add mac/MagicKeysCore
git commit -m "mac: K1 report parsing with validation"
```

---

### Task 3: Action and config models (TDD)

**Files:**
- Create: `mac/MagicKeysCore/Sources/MagicKeysCore/Actions.swift`
- Create: `mac/MagicKeysCore/Tests/MagicKeysCoreTests/ActionsTests.swift`

- [ ] **Step 1: Write the failing tests**

`ActionsTests.swift`:

```swift
import XCTest
@testable import MagicKeysCore

final class ActionsTests: XCTestCase {
    func testActionConfigRoundTripsThroughJSON() throws {
        let actions: [ActionConfig] = [
            .openApp(bundleID: "com.apple.Music"),
            .openURL(urlString: "https://usemagic.io"),
            .keystroke(keyCode: 15, modifiers: [.command, .shift]),
            .media(command: .playPause),
            .shellScript(script: "echo hi"),
        ]
        let data = try JSONEncoder().encode(actions)
        let decoded = try JSONDecoder().decode([ActionConfig].self, from: data)
        XCTAssertEqual(decoded, actions)
    }

    func testDefaultConfigHasThreeEmptyBindings() {
        let config = K1Config.makeDefault()
        XCTAssertEqual(config.keys.count, 3)
        for binding in config.keys {
            XCTAssertNil(binding.tap)
            XCTAssertNil(binding.doubleTap)
            XCTAssertNil(binding.hold)
        }
    }

    func testBindingLookupByGesture() {
        var config = K1Config.makeDefault()
        config.keys[1].doubleTap = .media(command: .mute)
        XCTAssertEqual(config.action(for: .doubleTap(key: 1)), .media(command: .mute))
        XCTAssertNil(config.action(for: .tap(key: 1)))
        XCTAssertNil(config.action(for: .doubleTap(key: 0)))
        XCTAssertNil(config.action(for: .tap(key: 9)))  // out of range is nil, not a crash
    }
}
```

- [ ] **Step 2: Run tests to verify they fail**

Run: `cd mac/MagicKeysCore && swift test`
Expected: compile errors — `ActionConfig`, `K1Config`, `Gesture` don't exist yet. (`Gesture` is defined here; the engine that emits it comes in Task 4.)

- [ ] **Step 3: Write the implementation**

`Actions.swift`:

```swift
import Foundation

public enum Gesture: Equatable, Sendable {
    case tap(key: Int)
    case doubleTap(key: Int)
    case hold(key: Int)
}

public enum KeyModifier: String, Codable, CaseIterable, Sendable {
    case command, shift, option, control
}

public enum MediaCommand: String, Codable, CaseIterable, Sendable {
    case playPause, volumeUp, volumeDown, mute
}

public enum ActionConfig: Codable, Equatable, Sendable {
    case openApp(bundleID: String)
    case openURL(urlString: String)
    case keystroke(keyCode: UInt16, modifiers: [KeyModifier])
    case media(command: MediaCommand)
    case shellScript(script: String)
}

public struct KeyBinding: Codable, Equatable, Sendable {
    public var tap: ActionConfig?
    public var doubleTap: ActionConfig?
    public var hold: ActionConfig?

    public init(tap: ActionConfig? = nil, doubleTap: ActionConfig? = nil, hold: ActionConfig? = nil) {
        self.tap = tap
        self.doubleTap = doubleTap
        self.hold = hold
    }
}

public struct GestureTiming: Codable, Equatable, Sendable {
    public var doubleTapWindow: TimeInterval
    public var holdThreshold: TimeInterval

    public init(doubleTapWindow: TimeInterval = 0.3, holdThreshold: TimeInterval = 0.4) {
        self.doubleTapWindow = doubleTapWindow
        self.holdThreshold = holdThreshold
    }
}

public struct K1Config: Codable, Equatable, Sendable {
    public var keys: [KeyBinding]
    public var timing: GestureTiming

    public static func makeDefault() -> K1Config {
        K1Config(keys: Array(repeating: KeyBinding(), count: K1Protocol.keyCount),
                 timing: GestureTiming())
    }

    public func action(for gesture: Gesture) -> ActionConfig? {
        switch gesture {
        case .tap(let key): return keys.indices.contains(key) ? keys[key].tap : nil
        case .doubleTap(let key): return keys.indices.contains(key) ? keys[key].doubleTap : nil
        case .hold(let key): return keys.indices.contains(key) ? keys[key].hold : nil
        }
    }
}
```

- [ ] **Step 4: Run tests to verify they pass**

Run: `cd mac/MagicKeysCore && swift test`
Expected: `Executed 11 tests, with 0 failures`.

- [ ] **Step 5: Commit**

```bash
git add mac/MagicKeysCore
git commit -m "mac: action/config models with Codable round-trip"
```

---

### Task 4: GestureEngine (TDD)

Pure logic, no timers: callers feed events with explicit timestamps and are told the next
deadline via `nextDeadline`; when it passes they call `expire(at:)`. This makes every
timing behavior unit-testable and lets the pipeline (Task 8) own the actual Timer.

State machine per key: `idle → firstDown → (release before hold) → awaitingSecondTap →
(second press) → secondDown`. Hold fires from `firstDown`/`secondDown` via `expire` when
held ≥ `holdThreshold`; tap fires via `expire` when the double-tap window lapses;
double-tap fires immediately on the second release.

**Files:**
- Create: `mac/MagicKeysCore/Sources/MagicKeysCore/GestureEngine.swift`
- Create: `mac/MagicKeysCore/Tests/MagicKeysCoreTests/GestureEngineTests.swift`

- [ ] **Step 1: Write the failing tests**

`GestureEngineTests.swift`:

```swift
import XCTest
@testable import MagicKeysCore

final class GestureEngineTests: XCTestCase {
    private var engine: GestureEngine!

    override func setUp() {
        engine = GestureEngine(keyCount: 3, timing: GestureTiming(doubleTapWindow: 0.3, holdThreshold: 0.4))
    }

    private func down(_ key: Int, at t: TimeInterval) -> [Gesture] {
        engine.handle(KeyEvent(key: key, isDown: true, seq: 0), at: t)
    }

    private func up(_ key: Int, at t: TimeInterval) -> [Gesture] {
        engine.handle(KeyEvent(key: key, isDown: false, seq: 0), at: t)
    }

    func testTapFiresAfterDoubleTapWindow() {
        XCTAssertEqual(down(0, at: 0.0), [])
        XCTAssertEqual(up(0, at: 0.1), [])
        XCTAssertEqual(engine.nextDeadline, 0.4)  // 0.1 + 0.3 window
        XCTAssertEqual(engine.expire(at: 0.4), [.tap(key: 0)])
        XCTAssertNil(engine.nextDeadline)
    }

    func testDoubleTapFiresOnSecondRelease() {
        _ = down(0, at: 0.0)
        _ = up(0, at: 0.1)
        _ = down(0, at: 0.25)
        XCTAssertEqual(up(0, at: 0.35), [.doubleTap(key: 0)])
        XCTAssertNil(engine.nextDeadline)
    }

    func testHoldFiresAtThresholdAndReleaseIsSilent() {
        XCTAssertEqual(down(0, at: 0.0), [])
        XCTAssertEqual(engine.nextDeadline, 0.4)  // hold threshold
        XCTAssertEqual(engine.expire(at: 0.4), [.hold(key: 0)])
        XCTAssertEqual(up(0, at: 1.0), [])
    }

    func testLongPressReleasedBeforeExpireStillCountsAsHold() {
        _ = down(0, at: 0.0)
        XCTAssertEqual(up(0, at: 0.5), [.hold(key: 0)])  // expire never called
    }

    func testSecondPressHeldBecomesHold() {
        _ = down(0, at: 0.0)
        _ = up(0, at: 0.1)
        _ = down(0, at: 0.2)
        XCTAssertEqual(engine.expire(at: 0.6), [.hold(key: 0)])  // 0.2 + 0.4
        XCTAssertEqual(up(0, at: 0.7), [])
    }

    func testTwoSlowTapsAreTwoTaps() {
        _ = down(0, at: 0.0)
        _ = up(0, at: 0.1)
        XCTAssertEqual(engine.expire(at: 0.4), [.tap(key: 0)])
        _ = down(0, at: 0.5)
        _ = up(0, at: 0.6)
        XCTAssertEqual(engine.expire(at: 0.9), [.tap(key: 0)])
    }

    func testKeysAreIndependent() {
        _ = down(0, at: 0.0)
        _ = down(1, at: 0.05)
        _ = up(0, at: 0.1)
        _ = up(1, at: 0.15)
        let gestures = engine.expire(at: 0.5)
        XCTAssertEqual(Set(gestures.map(String.init(describing:))),
                       Set([Gesture.tap(key: 0), Gesture.tap(key: 1)].map(String.init(describing:))))
    }

    func testNextDeadlineIsEarliestAcrossKeys() {
        _ = down(0, at: 0.0)   // hold deadline 0.4
        _ = down(1, at: 0.1)   // hold deadline 0.5
        XCTAssertEqual(engine.nextDeadline, 0.4)
    }

    func testOutOfRangeKeyIsIgnored() {
        XCTAssertEqual(engine.handle(KeyEvent(key: 9, isDown: true, seq: 0), at: 0), [])
    }
}
```

- [ ] **Step 2: Run tests to verify they fail**

Run: `cd mac/MagicKeysCore && swift test`
Expected: compile errors — `GestureEngine` doesn't exist yet.

- [ ] **Step 3: Write the implementation**

`GestureEngine.swift`:

```swift
import Foundation

/// Turns raw key down/up events into tap / doubleTap / hold gestures.
/// Pure logic: no timers. Callers watch `nextDeadline` and call `expire(at:)`
/// when it passes.
public final class GestureEngine {
    private enum KeyState: Equatable {
        case idle
        case firstDown(since: TimeInterval)
        case awaitingSecondTap(deadline: TimeInterval)
        case secondDown(since: TimeInterval)
        case holdFired
    }

    private let timing: GestureTiming
    private var states: [KeyState]

    public init(keyCount: Int = K1Protocol.keyCount, timing: GestureTiming = GestureTiming()) {
        self.timing = timing
        self.states = Array(repeating: .idle, count: keyCount)
    }

    public func handle(_ event: KeyEvent, at time: TimeInterval) -> [Gesture] {
        guard states.indices.contains(event.key) else { return [] }
        let key = event.key
        switch (states[key], event.isDown) {
        case (.idle, true):
            states[key] = .firstDown(since: time)
            return []
        case (.firstDown(let since), false):
            if time - since >= timing.holdThreshold {
                states[key] = .idle
                return [.hold(key: key)]
            }
            states[key] = .awaitingSecondTap(deadline: time + timing.doubleTapWindow)
            return []
        case (.awaitingSecondTap, true):
            states[key] = .secondDown(since: time)
            return []
        case (.secondDown(let since), false):
            states[key] = .idle
            if time - since >= timing.holdThreshold {
                return [.hold(key: key)]
            }
            return [.doubleTap(key: key)]
        case (.holdFired, false):
            states[key] = .idle
            return []
        default:
            return []  // duplicate down/up in same state — ignore
        }
    }

    public var nextDeadline: TimeInterval? {
        states.compactMap { state -> TimeInterval? in
            switch state {
            case .firstDown(let since), .secondDown(let since):
                return since + timing.holdThreshold
            case .awaitingSecondTap(let deadline):
                return deadline
            case .idle, .holdFired:
                return nil
            }
        }.min()
    }

    public func expire(at time: TimeInterval) -> [Gesture] {
        var fired: [Gesture] = []
        for key in states.indices {
            switch states[key] {
            case .firstDown(let since), .secondDown(let since):
                if time - since >= timing.holdThreshold {
                    states[key] = .holdFired
                    fired.append(.hold(key: key))
                }
            case .awaitingSecondTap(let deadline):
                if time >= deadline {
                    states[key] = .idle
                    fired.append(.tap(key: key))
                }
            case .idle, .holdFired:
                break
            }
        }
        return fired
    }
}
```

- [ ] **Step 4: Run tests to verify they pass**

Run: `cd mac/MagicKeysCore && swift test`
Expected: `Executed 20 tests, with 0 failures`.

- [ ] **Step 5: Commit**

```bash
git add mac/MagicKeysCore
git commit -m "mac: gesture engine — tap/double-tap/hold state machine"
```

---

### Task 5: ConfigStore (TDD)

**Files:**
- Create: `mac/MagicKeysCore/Sources/MagicKeysCore/ConfigStore.swift`
- Create: `mac/MagicKeysCore/Tests/MagicKeysCoreTests/ConfigStoreTests.swift`

- [ ] **Step 1: Write the failing tests**

`ConfigStoreTests.swift`:

```swift
import XCTest
@testable import MagicKeysCore

final class ConfigStoreTests: XCTestCase {
    private var dir: URL!

    override func setUpWithError() throws {
        dir = FileManager.default.temporaryDirectory
            .appendingPathComponent("MagicKeysTests-\(UUID().uuidString)")
    }

    override func tearDownWithError() throws {
        try? FileManager.default.removeItem(at: dir)
    }

    func testMissingFileYieldsDefaultConfig() {
        let store = ConfigStore(directory: dir)
        XCTAssertEqual(store.config, K1Config.makeDefault())
    }

    func testUpdatePersistsAndReloads() {
        let store = ConfigStore(directory: dir)
        store.update { $0.keys[0].tap = .openURL(urlString: "https://usemagic.io") }

        let reloaded = ConfigStore(directory: dir)
        XCTAssertEqual(reloaded.config.keys[0].tap, .openURL(urlString: "https://usemagic.io"))
    }

    func testCorruptFileFallsBackToDefault() throws {
        try FileManager.default.createDirectory(at: dir, withIntermediateDirectories: true)
        try Data("not json".utf8).write(to: dir.appendingPathComponent("config.json"))
        let store = ConfigStore(directory: dir)
        XCTAssertEqual(store.config, K1Config.makeDefault())
    }
}
```

- [ ] **Step 2: Run tests to verify they fail**

Run: `cd mac/MagicKeysCore && swift test`
Expected: compile errors — `ConfigStore` doesn't exist yet.

- [ ] **Step 3: Write the implementation**

`ConfigStore.swift`:

```swift
import Foundation
import Combine

/// Loads/saves K1Config as JSON in `directory`/config.json.
/// Falls back to the default config on missing or corrupt files.
public final class ConfigStore: ObservableObject {
    @Published public private(set) var config: K1Config

    private let fileURL: URL

    public static func defaultDirectory() -> URL {
        FileManager.default.urls(for: .applicationSupportDirectory, in: .userDomainMask)[0]
            .appendingPathComponent("MagicKeys")
    }

    public init(directory: URL = ConfigStore.defaultDirectory()) {
        self.fileURL = directory.appendingPathComponent("config.json")
        if let data = try? Data(contentsOf: fileURL),
           let loaded = try? JSONDecoder().decode(K1Config.self, from: data) {
            self.config = loaded
        } else {
            self.config = K1Config.makeDefault()
        }
    }

    public func update(_ mutate: (inout K1Config) -> Void) {
        var updated = config
        mutate(&updated)
        config = updated
        save()
    }

    private func save() {
        do {
            try FileManager.default.createDirectory(
                at: fileURL.deletingLastPathComponent(), withIntermediateDirectories: true)
            let encoder = JSONEncoder()
            encoder.outputFormatting = [.prettyPrinted, .sortedKeys]
            try encoder.encode(config).write(to: fileURL, options: .atomic)
        } catch {
            // Persisting config is best-effort; the in-memory config stays authoritative.
            NSLog("MagicKeys: failed to save config: \(error)")
        }
    }
}
```

- [ ] **Step 4: Run tests to verify they pass**

Run: `cd mac/MagicKeysCore && swift test`
Expected: `Executed 23 tests, with 0 failures`.

- [ ] **Step 5: Commit**

```bash
git add mac/MagicKeysCore
git commit -m "mac: JSON config store with corrupt-file fallback"
```

---

### Task 6: App scaffold (XcodeGen + MenuBarExtra)

**Files:**
- Create: `mac/project.yml`
- Create: `mac/MagicKeys/Sources/MagicKeysApp.swift`
- Create: `mac/MagicKeys/Sources/AppModel.swift`

- [ ] **Step 1: Write project.yml**

```yaml
name: MagicKeys
options:
  bundleIdPrefix: io.usemagic
  deploymentTarget:
    macOS: "14.0"
packages:
  MagicKeysCore:
    path: MagicKeysCore
targets:
  MagicKeys:
    type: application
    platform: macOS
    sources:
      - path: MagicKeys/Sources
    dependencies:
      - package: MagicKeysCore
    settings:
      base:
        PRODUCT_BUNDLE_IDENTIFIER: io.usemagic.magickeys
        GENERATE_INFOPLIST_FILE: YES
        INFOPLIST_KEY_LSUIElement: YES   # menu-bar app, no Dock icon
        CODE_SIGN_IDENTITY: "-"          # ad-hoc signing for dev builds
        SWIFT_VERSION: "5.9"
```

- [ ] **Step 2: Write the app entry point and model**

`mac/MagicKeys/Sources/AppModel.swift`:

```swift
import Foundation
import MagicKeysCore

@MainActor
final class AppModel: ObservableObject {
    @Published var isConnected = false
    @Published var deviceInfo: DeviceInfo?

    let configStore = ConfigStore()

    // HIDService / GesturePipeline / ActionEngine attach in later tasks.
    func start() {}
}
```

`mac/MagicKeys/Sources/MagicKeysApp.swift`:

```swift
import SwiftUI
import MagicKeysCore

@main
struct MagicKeysApp: App {
    @StateObject private var model = AppModel()
    @Environment(\.openWindow) private var openWindow

    var body: some Scene {
        MenuBarExtra("Magic Keys",
                     systemImage: model.isConnected ? "circle.grid.3x1.fill" : "circle.grid.3x1") {
            Text(model.isConnected
                 ? "K1 connected" + (model.deviceInfo.map { " — fw \($0.firmwareMajor).\($0.firmwareMinor)" } ?? "")
                 : "K1 not connected")
            Divider()
            Button("Configure…") {
                openWindow(id: "config")
                NSApp.activate(ignoringOtherApps: true)
            }
            Divider()
            Button("Quit Magic Keys") { NSApp.terminate(nil) }
        }

        Window("Magic Keys", id: "config") {
            Text("Configuration UI lands in Task 10")
                .frame(minWidth: 520, minHeight: 320)
                .environmentObject(model)
        }
        .windowResizability(.contentSize)
    }
}
```

- [ ] **Step 3: Generate the project and build**

Run: `cd mac && xcodegen generate && xcodebuild -project MagicKeys.xcodeproj -scheme MagicKeys -configuration Debug build`
Expected: `** BUILD SUCCEEDED **`. If `xcodegen` is missing: `brew install xcodegen`.

- [ ] **Step 4: Add generated project to gitignore and commit**

Append to `.gitignore` (repo root):

```
mac/MagicKeys.xcodeproj/
```

```bash
git add mac/project.yml mac/MagicKeys/Sources .gitignore
git commit -m "mac: XcodeGen app scaffold with MenuBarExtra shell"
```

---

### Task 7: HIDService

**Files:**
- Create: `mac/MagicKeys/Sources/HIDService.swift`

The only unit that touches IOKit. Runs on the main run loop; publishes typed messages
and connection state via closures. Because the K1 uses a vendor usage page (not a
keyboard page), reading it needs no Input Monitoring permission.

- [ ] **Step 1: Write HIDService.swift**

```swift
import Foundation
import IOKit.hid
import MagicKeysCore

/// Owns the IOHIDManager session for the K1: hotplug, input reports, GET_INFO.
/// All callbacks are delivered on the main run loop.
final class HIDService {
    var onMessage: ((K1Message) -> Void)?
    var onConnectionChange: ((Bool) -> Void)?

    private var manager: IOHIDManager?
    private var device: IOHIDDevice?
    // Must outlive the registered callback, so it's a stable allocation,
    // not a Swift Array (whose withUnsafe... pointer may not escape).
    private let reportBuffer = UnsafeMutablePointer<UInt8>.allocate(capacity: K1Protocol.reportSize)
    private var lastSeq: UInt8?

    deinit { reportBuffer.deallocate() }

    func start() {
        let manager = IOHIDManagerCreate(kCFAllocatorDefault, IOOptionBits(kIOHIDOptionsTypeNone))
        self.manager = manager

        let matching: [String: Any] = [
            kIOHIDVendorIDKey: K1Protocol.vendorID,
            kIOHIDProductIDKey: K1Protocol.productID,
        ]
        IOHIDManagerSetDeviceMatching(manager, matching as CFDictionary)

        let context = Unmanaged.passUnretained(self).toOpaque()
        IOHIDManagerRegisterDeviceMatchingCallback(manager, { context, _, _, device in
            let service = Unmanaged<HIDService>.fromOpaque(context!).takeUnretainedValue()
            service.deviceAttached(device)
        }, context)
        IOHIDManagerRegisterDeviceRemovalCallback(manager, { context, _, _, _ in
            let service = Unmanaged<HIDService>.fromOpaque(context!).takeUnretainedValue()
            service.deviceDetached()
        }, context)

        IOHIDManagerScheduleWithRunLoop(manager, CFRunLoopGetMain(), CFRunLoopMode.defaultMode.rawValue)
        IOHIDManagerOpen(manager, IOOptionBits(kIOHIDOptionsTypeNone))
    }

    private func deviceAttached(_ device: IOHIDDevice) {
        self.device = device
        lastSeq = nil

        let context = Unmanaged.passUnretained(self).toOpaque()
        IOHIDDeviceRegisterInputReportCallback(
            device, reportBuffer, K1Protocol.reportSize,
            { context, _, _, _, _, report, reportLength in
                let service = Unmanaged<HIDService>.fromOpaque(context!).takeUnretainedValue()
                let bytes = Array(UnsafeBufferPointer(start: report, count: reportLength))
                service.handleReport(bytes)
            }, context)

        onConnectionChange?(true)
        sendGetInfo()
    }

    private func deviceDetached() {
        device = nil
        onConnectionChange?(false)
    }

    private func handleReport(_ bytes: [UInt8]) {
        guard let message = K1Protocol.parse(bytes) else {
            NSLog("MagicKeys: dropped malformed report \(bytes)")
            return
        }
        if case .keyEvent(let event) = message {
            if let last = lastSeq, event.seq != last &+ 1 {
                NSLog("MagicKeys: sequence gap \(last) -> \(event.seq)")
            }
            lastSeq = event.seq
        }
        onMessage?(message)
    }

    func sendGetInfo() {
        guard let device else { return }
        var report = K1Protocol.getInfoReport
        IOHIDDeviceSetReport(device, kIOHIDReportTypeOutput, 0, &report, report.count)
    }
}
```

- [ ] **Step 2: Wire into AppModel**

In `AppModel.swift`, replace the class body:

```swift
@MainActor
final class AppModel: ObservableObject {
    @Published var isConnected = false
    @Published var deviceInfo: DeviceInfo?

    let configStore = ConfigStore()
    private let hidService = HIDService()

    func start() {
        hidService.onConnectionChange = { [weak self] connected in
            Task { @MainActor in
                self?.isConnected = connected
                if !connected { self?.deviceInfo = nil }
            }
        }
        hidService.onMessage = { [weak self] message in
            Task { @MainActor in self?.handle(message) }
        }
        hidService.start()
    }

    private func handle(_ message: K1Message) {
        switch message {
        case .info(let info):
            deviceInfo = info
        case .keyEvent(let event):
            NSLog("MagicKeys: key \(event.key) \(event.isDown ? "down" : "up")")
            // GesturePipeline consumes these in Task 8.
        }
    }
}
```

And in `MagicKeysApp.swift`, replace the `MenuBarExtra` scene with the label form. The menu *content* only exists while the menu is open, so `model.start()` must hang off the *label*, which is always rendered in the status bar:

```swift
        MenuBarExtra {
            Text(model.isConnected
                 ? "K1 connected" + (model.deviceInfo.map { " — fw \($0.firmwareMajor).\($0.firmwareMinor)" } ?? "")
                 : "K1 not connected")
            Divider()
            Button("Configure…") {
                openWindow(id: "config")
                NSApp.activate(ignoringOtherApps: true)
            }
            Divider()
            Button("Quit Magic Keys") { NSApp.terminate(nil) }
        } label: {
            Image(systemName: model.isConnected ? "circle.grid.3x1.fill" : "circle.grid.3x1")
                .task { model.start() }
        }
```

- [ ] **Step 3: Build and verify against hardware if present**

Run: `cd mac && xcodegen generate && xcodebuild -project MagicKeys.xcodeproj -scheme MagicKeys -configuration Debug build`
Expected: `** BUILD SUCCEEDED **`.

With a flashed K1 plugged in, run the built app (`open` the .app from DerivedData or run from Xcode): the menu-bar icon fills in, the menu shows `K1 connected — fw 0.1`, and Console.app (filter `MagicKeys`) shows key events on press.

- [ ] **Step 4: Commit**

```bash
git add mac/MagicKeys/Sources
git commit -m "mac: HIDService — hotplug, report parsing, GET_INFO"
```

---

### Task 8: GesturePipeline + virtual K1

**Files:**
- Create: `mac/MagicKeys/Sources/GesturePipeline.swift`
- Modify: `mac/MagicKeys/Sources/AppModel.swift`
- Modify: `mac/MagicKeys/Sources/MagicKeysApp.swift`

- [ ] **Step 1: Write GesturePipeline.swift**

```swift
import Foundation
import MagicKeysCore

/// Feeds key events into the GestureEngine and owns the deadline timer.
/// Main-actor bound: HID callbacks already arrive on the main run loop.
@MainActor
final class GesturePipeline {
    var onGesture: ((Gesture) -> Void)?

    private let engine: GestureEngine
    private var timer: Timer?
    private var clock: () -> TimeInterval

    init(timing: GestureTiming, clock: @escaping () -> TimeInterval = { ProcessInfo.processInfo.systemUptime }) {
        self.engine = GestureEngine(timing: timing)
        self.clock = clock
    }

    func handle(_ event: KeyEvent) {
        emit(engine.handle(event, at: clock()))
        reschedule()
    }

    private func expire() {
        emit(engine.expire(at: clock()))
        reschedule()
    }

    private func emit(_ gestures: [Gesture]) {
        for gesture in gestures { onGesture?(gesture) }
    }

    private func reschedule() {
        timer?.invalidate()
        timer = nil
        guard let deadline = engine.nextDeadline else { return }
        let delay = max(0, deadline - clock())
        timer = Timer.scheduledTimer(withTimeInterval: delay, repeats: false) { [weak self] _ in
            Task { @MainActor in self?.expire() }
        }
    }
}
```

- [ ] **Step 2: Wire into AppModel and add the virtual K1**

In `AppModel.swift`, replace the class body:

```swift
@MainActor
final class AppModel: ObservableObject {
    @Published var isConnected = false
    @Published var deviceInfo: DeviceInfo?
    @Published var lastGesture: Gesture?

    let configStore = ConfigStore()
    private let hidService = HIDService()
    private var pipeline: GesturePipeline?

    func start() {
        pipeline = makePipeline()

        hidService.onConnectionChange = { [weak self] connected in
            Task { @MainActor in
                self?.isConnected = connected
                if !connected {
                    self?.deviceInfo = nil
                    // Drop in-flight gesture state (spec: reset on disconnect).
                    self?.pipeline = self?.makePipeline()
                }
            }
        }
        hidService.onMessage = { [weak self] message in
            Task { @MainActor in self?.handle(message) }
        }
        hidService.start()
    }

    private func makePipeline() -> GesturePipeline {
        let pipeline = GesturePipeline(timing: configStore.config.timing)
        pipeline.onGesture = { [weak self] gesture in
            self?.lastGesture = gesture
            NSLog("MagicKeys: gesture \(gesture)")
            // ActionEngine executes these in Task 9.
        }
        return pipeline
    }

    private func handle(_ message: K1Message) {
        switch message {
        case .info(let info): deviceInfo = info
        case .keyEvent(let event): pipeline?.handle(event)
        }
    }

    #if DEBUG
    private var virtualSeq: UInt8 = 0
    /// Simulates a physical press: down now, up after `duration`.
    func simulatePress(key: Int, duration: TimeInterval = 0.1) {
        virtualSeq &+= 1
        pipeline?.handle(KeyEvent(key: key, isDown: true, seq: virtualSeq))
        virtualSeq &+= 1
        let seq = virtualSeq
        DispatchQueue.main.asyncAfter(deadline: .now() + duration) { [weak self] in
            self?.pipeline?.handle(KeyEvent(key: key, isDown: false, seq: seq))
        }
    }
    #endif
}
```

In `MagicKeysApp.swift`, add a DEBUG section to the `MenuBarExtra` content, just above the Quit button's `Divider()`:

```swift
            #if DEBUG
            Divider()
            Menu("Virtual K1") {
                ForEach(0..<3, id: \.self) { key in
                    Button("Key \(key + 1): tap") { model.simulatePress(key: key) }
                    Button("Key \(key + 1): double tap") {
                        model.simulatePress(key: key)
                        DispatchQueue.main.asyncAfter(deadline: .now() + 0.2) {
                            model.simulatePress(key: key)
                        }
                    }
                    Button("Key \(key + 1): hold") { model.simulatePress(key: key, duration: 0.6) }
                }
            }
            #endif
```

- [ ] **Step 3: Build and verify with the virtual K1**

Run: `cd mac && xcodegen generate && xcodebuild -project MagicKeys.xcodeproj -scheme MagicKeys -configuration Debug build`
Expected: `** BUILD SUCCEEDED **`.

Run the app; use Virtual K1 → "Key 1: tap" / "double tap" / "hold" and confirm Console.app logs `gesture tap(key: 0)`, `gesture doubleTap(key: 0)`, `gesture hold(key: 0)` respectively.

- [ ] **Step 4: Commit**

```bash
git add mac/MagicKeys/Sources
git commit -m "mac: gesture pipeline with deadline timer + DEBUG virtual K1"
```

---

### Task 9: ActionEngine

**Files:**
- Create: `mac/MagicKeys/Sources/ActionEngine.swift`
- Create: `mac/MagicKeys/Sources/MediaKey.swift`
- Modify: `mac/MagicKeys/Sources/AppModel.swift`

- [ ] **Step 1: Write MediaKey.swift**

```swift
import AppKit

/// Posts media keys as system-defined NSEvents (the same mechanism the
/// keyboard's media keys use). No special permission required.
enum MediaKey: UInt32 {
    case playPause = 16  // NX_KEYTYPE_PLAY
    case volumeUp = 0    // NX_KEYTYPE_SOUND_UP
    case volumeDown = 1  // NX_KEYTYPE_SOUND_DOWN
    case mute = 7        // NX_KEYTYPE_MUTE

    func post() {
        postPhase(down: true)
        postPhase(down: false)
    }

    private func postPhase(down: Bool) {
        let flags: NSEvent.ModifierFlags = down ? .init(rawValue: 0xA00) : .init(rawValue: 0xB00)
        let data1 = Int((rawValue << 16) | (down ? 0x0A00 : 0x0B00))
        guard let event = NSEvent.otherEvent(
            with: .systemDefined, location: .zero, modifierFlags: flags,
            timestamp: 0, windowNumber: 0, context: nil,
            subtype: 8, data1: data1, data2: -1) else { return }
        event.cgEvent?.post(tap: .cghidEventTap)
    }
}
```

- [ ] **Step 2: Write ActionEngine.swift**

```swift
import AppKit
import Foundation
import MagicKeysCore
import UserNotifications

/// Executes a configured action. Failures notify the user; they never throw
/// past this boundary.
@MainActor
final class ActionEngine {
    func run(_ action: ActionConfig) {
        switch action {
        case .openApp(let bundleID):
            guard let url = NSWorkspace.shared.urlForApplication(withBundleIdentifier: bundleID) else {
                notifyFailure("No app found for \(bundleID)")
                return
            }
            NSWorkspace.shared.openApplication(at: url, configuration: .init())

        case .openURL(let urlString):
            guard let url = URL(string: urlString) else {
                notifyFailure("Invalid URL: \(urlString)")
                return
            }
            NSWorkspace.shared.open(url)

        case .keystroke(let keyCode, let modifiers):
            postKeystroke(keyCode: keyCode, modifiers: modifiers)

        case .media(let command):
            mediaKey(for: command).post()

        case .shellScript(let script):
            runShell(script)
        }
    }

    private func mediaKey(for command: MediaCommand) -> MediaKey {
        switch command {
        case .playPause: return .playPause
        case .volumeUp: return .volumeUp
        case .volumeDown: return .volumeDown
        case .mute: return .mute
        }
    }

    private func postKeystroke(keyCode: UInt16, modifiers: [KeyModifier]) {
        // Prompts for Accessibility permission on first use.
        let options = [kAXTrustedCheckOptionPrompt.takeUnretainedValue() as String: true] as CFDictionary
        guard AXIsProcessTrustedWithOptions(options) else {
            notifyFailure("Grant Accessibility permission to send keystrokes, then try again.")
            return
        }
        var flags: CGEventFlags = []
        for modifier in modifiers {
            switch modifier {
            case .command: flags.insert(.maskCommand)
            case .shift: flags.insert(.maskShift)
            case .option: flags.insert(.maskAlternate)
            case .control: flags.insert(.maskControl)
            }
        }
        let source = CGEventSource(stateID: .hidSystemState)
        for down in [true, false] {
            guard let event = CGEvent(keyboardEventSource: source, virtualKey: keyCode, keyDown: down) else { continue }
            event.flags = flags
            event.post(tap: .cghidEventTap)
        }
    }

    private func runShell(_ script: String) {
        let process = Process()
        process.executableURL = URL(fileURLWithPath: "/bin/zsh")
        process.arguments = ["-lc", script]
        process.terminationHandler = { [weak self] process in
            if process.terminationStatus != 0 {
                Task { @MainActor in
                    self?.notifyFailure("Script exited with status \(process.terminationStatus)")
                }
            }
        }
        do {
            try process.run()
        } catch {
            notifyFailure("Could not run script: \(error.localizedDescription)")
        }
    }

    private func notifyFailure(_ message: String) {
        NSLog("MagicKeys: action failed — \(message)")
        let center = UNUserNotificationCenter.current()
        center.requestAuthorization(options: [.alert]) { granted, _ in
            guard granted else { return }
            let content = UNMutableNotificationContent()
            content.title = "Magic Keys"
            content.body = message
            center.add(UNNotificationRequest(identifier: UUID().uuidString,
                                             content: content, trigger: nil))
        }
    }
}
```

- [ ] **Step 3: Wire into AppModel**

In `AppModel.swift`, add a property below `configStore`:

```swift
    private let actionEngine = ActionEngine()
```

and replace the `pipeline.onGesture` closure inside `makePipeline()`:

```swift
        pipeline.onGesture = { [weak self] gesture in
            guard let self else { return }
            self.lastGesture = gesture
            if let action = self.configStore.config.action(for: gesture) {
                self.actionEngine.run(action)
            }
        }
```

- [ ] **Step 4: Build and verify end-to-end via virtual K1**

Run: `cd mac && xcodegen generate && xcodebuild -project MagicKeys.xcodeproj -scheme MagicKeys -configuration Debug build`
Expected: `** BUILD SUCCEEDED **`.

Manual check: edit `~/Library/Application Support/MagicKeys/config.json` to bind key 0 tap to `{"openURL":{"urlString":"https://usemagic.io"}}` (create via one app launch first, or write the file). Run the app, Virtual K1 → "Key 1: tap" — the URL opens.

- [ ] **Step 5: Commit**

```bash
git add mac/MagicKeys/Sources
git commit -m "mac: action engine — open app/URL, keystroke, media, shell"
```

---

### Task 10: Configuration UI

**Files:**
- Create: `mac/MagicKeys/Sources/UI/ConfigView.swift`
- Create: `mac/MagicKeys/Sources/UI/ActionPickerView.swift`
- Modify: `mac/MagicKeys/Sources/MagicKeysApp.swift`

Logitech-style: device strip with 3 selectable keys on the left, gesture slots for the
selected key on the right. Functional first; visual polish is a later pass.

- [ ] **Step 1: Write ActionPickerView.swift**

```swift
import SwiftUI
import MagicKeysCore

/// Editor for one gesture slot: action type picker + parameters.
struct ActionPickerView: View {
    let title: String
    @Binding var action: ActionConfig?

    private enum Kind: String, CaseIterable, Identifiable {
        case none = "None"
        case openApp = "Open App"
        case openURL = "Open URL"
        case keystroke = "Keystroke"
        case media = "Media"
        case shellScript = "Shell Script"
        var id: String { rawValue }
    }

    private var kind: Kind {
        switch action {
        case nil: return .none
        case .openApp: return .openApp
        case .openURL: return .openURL
        case .keystroke: return .keystroke
        case .media: return .media
        case .shellScript: return .shellScript
        }
    }

    var body: some View {
        VStack(alignment: .leading, spacing: 6) {
            Text(title).font(.headline)
            Picker("Action", selection: Binding(
                get: { kind },
                set: { newKind in
                    switch newKind {
                    case .none: action = nil
                    case .openApp: action = .openApp(bundleID: "")
                    case .openURL: action = .openURL(urlString: "")
                    case .keystroke: action = .keystroke(keyCode: 0, modifiers: [])
                    case .media: action = .media(command: .playPause)
                    case .shellScript: action = .shellScript(script: "")
                    }
                })) {
                ForEach(Kind.allCases) { kind in
                    Text(kind.rawValue).tag(kind)
                }
            }
            .labelsHidden()
            parameterFields
        }
        .padding(10)
        .background(RoundedRectangle(cornerRadius: 8).fill(Color(nsColor: .controlBackgroundColor)))
    }

    @ViewBuilder
    private var parameterFields: some View {
        switch action {
        case .openApp(let bundleID):
            TextField("Bundle ID (e.g. com.apple.Music)", text: Binding(
                get: { bundleID },
                set: { action = .openApp(bundleID: $0) }))
        case .openURL(let urlString):
            TextField("URL", text: Binding(
                get: { urlString },
                set: { action = .openURL(urlString: $0) }))
        case .keystroke(let keyCode, let modifiers):
            HStack {
                TextField("Key code", value: Binding(
                    get: { keyCode },
                    set: { action = .keystroke(keyCode: $0, modifiers: modifiers) }),
                    format: .number)
                    .frame(width: 80)
                ForEach(KeyModifier.allCases, id: \.self) { modifier in
                    Toggle(modifier.rawValue.capitalized, isOn: Binding(
                        get: { modifiers.contains(modifier) },
                        set: { on in
                            var updated = modifiers.filter { $0 != modifier }
                            if on { updated.append(modifier) }
                            action = .keystroke(keyCode: keyCode, modifiers: updated)
                        }))
                }
            }
        case .media(let command):
            Picker("Command", selection: Binding(
                get: { command },
                set: { action = .media(command: $0) })) {
                ForEach(MediaCommand.allCases, id: \.self) { command in
                    Text(command.rawValue).tag(command)
                }
            }
            .labelsHidden()
        case .shellScript(let script):
            TextField("Shell command", text: Binding(
                get: { script },
                set: { action = .shellScript(script: $0) }))
                .font(.system(.body, design: .monospaced))
        case nil:
            EmptyView()
        }
    }
}
```

- [ ] **Step 2: Write ConfigView.swift**

```swift
import SwiftUI
import MagicKeysCore

struct ConfigView: View {
    @EnvironmentObject private var model: AppModel
    @State private var selectedKey = 0

    var body: some View {
        HSplitView {
            devicePane
                .frame(minWidth: 180, maxWidth: 220, maxHeight: .infinity)
            bindingsPane
                .frame(minWidth: 340, maxWidth: .infinity, maxHeight: .infinity)
        }
        .frame(minWidth: 560, minHeight: 380)
    }

    private var devicePane: some View {
        VStack(spacing: 16) {
            Text(model.isConnected ? "K1 connected" : "K1 not connected")
                .font(.subheadline)
                .foregroundStyle(model.isConnected ? .primary : .secondary)
            // Stylized device: three keys in a vertical strip, like the
            // K1 sitting along the MacBook edge.
            VStack(spacing: 10) {
                ForEach(0..<3, id: \.self) { key in
                    Button {
                        selectedKey = key
                    } label: {
                        RoundedRectangle(cornerRadius: 8)
                            .fill(selectedKey == key ? Color.accentColor.opacity(0.35)
                                                     : Color(nsColor: .controlBackgroundColor))
                            .overlay(RoundedRectangle(cornerRadius: 8)
                                .strokeBorder(selectedKey == key ? Color.accentColor : .secondary.opacity(0.4)))
                            .overlay(Text("\(key + 1)").font(.title2.bold()))
                            .frame(width: 64, height: 64)
                    }
                    .buttonStyle(.plain)
                }
            }
            Spacer()
        }
        .padding()
    }

    private var bindingsPane: some View {
        ScrollView {
            VStack(alignment: .leading, spacing: 12) {
                Text("Key \(selectedKey + 1)").font(.title2.bold())
                ActionPickerView(title: "Tap", action: binding(\.tap))
                ActionPickerView(title: "Double Tap", action: binding(\.doubleTap))
                ActionPickerView(title: "Hold", action: binding(\.hold))
            }
            .padding()
        }
    }

    private func binding(_ keyPath: WritableKeyPath<KeyBinding, ActionConfig?>) -> Binding<ActionConfig?> {
        Binding(
            get: { model.configStore.config.keys[selectedKey][keyPath: keyPath] },
            set: { newValue in
                model.configStore.update { $0.keys[selectedKey][keyPath: keyPath] = newValue }
            })
    }
}
```

- [ ] **Step 3: Replace the config window placeholder**

In `MagicKeysApp.swift`, replace the `Window` scene's content:

```swift
        Window("Magic Keys", id: "config") {
            ConfigView()
                .environmentObject(model)
        }
        .windowResizability(.contentSize)
```

- [ ] **Step 4: Build and verify end-to-end**

Run: `cd mac && xcodegen generate && xcodebuild -project MagicKeys.xcodeproj -scheme MagicKeys -configuration Debug build`
Expected: `** BUILD SUCCEEDED **`.

Run the app → Configure…: select key 1, set Tap to Open URL `https://usemagic.io`; Virtual K1 → "Key 1: tap" opens the URL. Quit and relaunch: the binding survived (config.json).

- [ ] **Step 5: Commit**

```bash
git add mac/MagicKeys/Sources
git commit -m "mac: Logitech-style config UI — key strip + gesture slots"
```

---

### Task 11: Launch at login, polish, docs

**Files:**
- Modify: `mac/MagicKeys/Sources/MagicKeysApp.swift`
- Modify: `mac/README.md`
- Modify: `PROJECT_SUMMARY.md`

- [ ] **Step 1: Add launch-at-login toggle**

In `MagicKeysApp.swift`, add `import ServiceManagement` at the top, and add to the `MenuBarExtra` content directly under the `Button("Configure…") { ... }` block:

```swift
            Toggle("Launch at Login", isOn: Binding(
                get: { SMAppService.mainApp.status == .enabled },
                set: { enable in
                    do {
                        if enable { try SMAppService.mainApp.register() }
                        else { try SMAppService.mainApp.unregister() }
                    } catch {
                        NSLog("MagicKeys: launch-at-login failed: \(error)")
                    }
                }))
```

- [ ] **Step 2: Build**

Run: `cd mac && xcodegen generate && xcodebuild -project MagicKeys.xcodeproj -scheme MagicKeys -configuration Debug build`
Expected: `** BUILD SUCCEEDED **`.

- [ ] **Step 3: Replace mac/README.md**

```markdown
# Magic Keys

SwiftUI menu-bar companion app for the K1. Receives key events over vendor HID,
detects tap / double-tap / hold, and runs configured actions.

## Structure

- `MagicKeysCore/` — SwiftPM package: protocol parsing, gesture engine,
  config models/store. Test with `swift test` (no hardware needed).
- `MagicKeys/Sources/` — app target: HIDService (IOKit), GesturePipeline,
  ActionEngine, SwiftUI UI. Project generated by XcodeGen.

## Build

    brew install xcodegen   # once
    xcodegen generate
    xcodebuild -project MagicKeys.xcodeproj -scheme MagicKeys -configuration Debug build

Or open `MagicKeys.xcodeproj` in Xcode after `xcodegen generate`.

## Developing without hardware

DEBUG builds have a "Virtual K1" menu in the menu-bar extra that simulates
taps, double-taps, and holds on each key.

## Permissions

- Vendor HID input: none needed.
- Keystroke actions: Accessibility (prompted on first use).
- Failure notifications: Notifications (prompted on first failure).
```

- [ ] **Step 4: Update PROJECT_SUMMARY.md status**

Change the Mac app line in Current status to:

```markdown
- ✅ Magic Keys app: HID pipeline, gesture engine, action engine, config UI, virtual K1
```

- [ ] **Step 5: Commit**

```bash
git add mac/MagicKeys/Sources mac/README.md PROJECT_SUMMARY.md
git commit -m "mac: launch at login, README, status update"
```

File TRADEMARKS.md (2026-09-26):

# Trademarks

"Magic", "Magic Macropad", and the Magic logo are trademarks of Magic
Technologies Inc. They are **not** licensed under this repository's
CC BY-NC-SA 4.0 license. Section 2(b)(2) of that license grants no trademark
rights, and the logo artwork (`mac/MagicKeys/MagicIcon.icon/`) is excluded
from the license entirely.

**You may** use the names to refer to this project truthfully, for example
"a remix of Magic Macropad" or "a case for the Magic Macropad".

**Please don't** distribute a modified device, app, or firmware under the Magic
name or with the Magic logo. If you share a fork or remix:

- give it a different name,
- replace the app icon (`mac/MagicKeys/MagicIcon.icon/`), and
- change the USB manufacturer and product strings in
  `firmware/main/usb_hid.c`.

This project isn't affiliated with or endorsed by Apple Inc. Mac, MacBook, and
macOS are trademarks of Apple Inc.

Questions: [usemagic.io](https://usemagic.io)

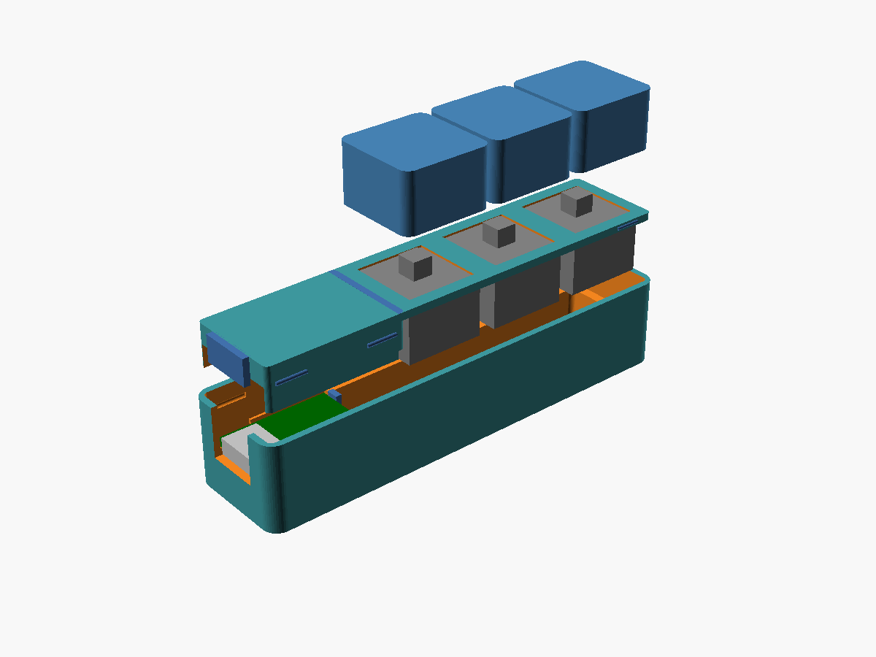
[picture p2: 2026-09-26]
cad/desk/v2/k1_desk_v2_exploded.png

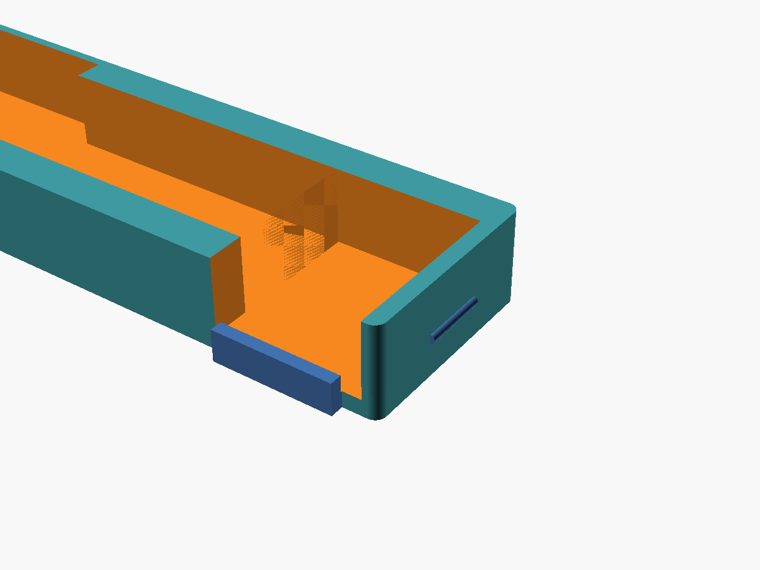
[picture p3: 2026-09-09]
cad/v5/k1_v5_deck_rear.png

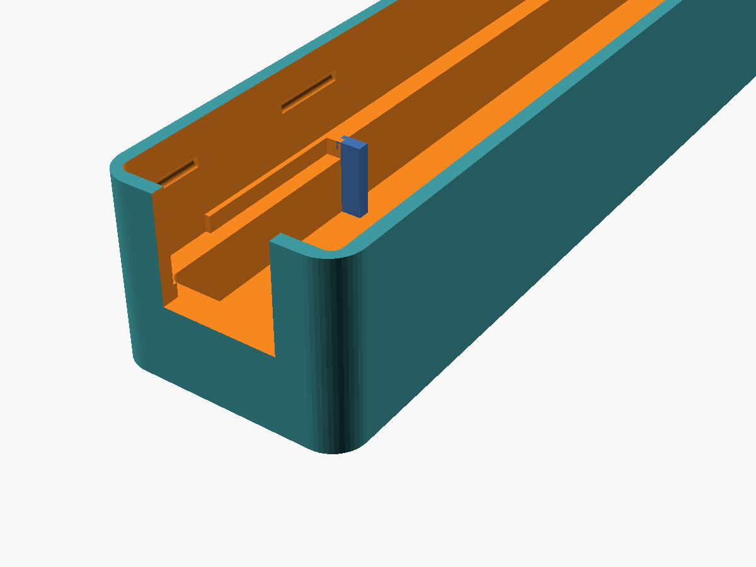
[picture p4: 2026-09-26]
cad/desk/v2/k1_desk_v2_tray_seat.png

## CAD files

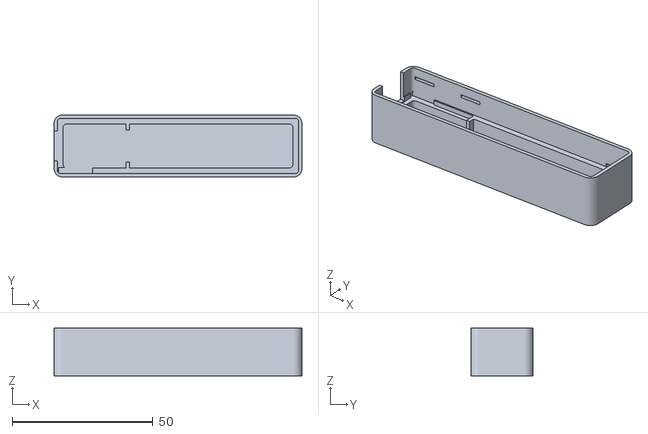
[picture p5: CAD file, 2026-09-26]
cad/desk/v2/k1_tray.stl
88.0 x 22.0 x 17.0

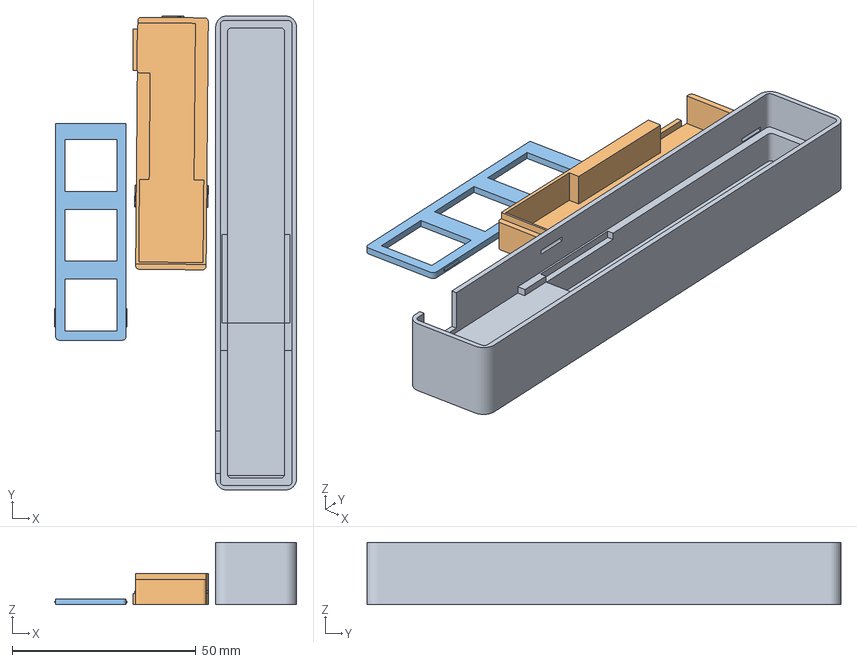
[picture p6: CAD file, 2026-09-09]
cad/v5/k1_v5_m.3mf
65.9 x 129.0 x 17.0 mm
k1_tray_mirror.stl
k1_deck_mirror.stl
k1_plate_mirror.stl

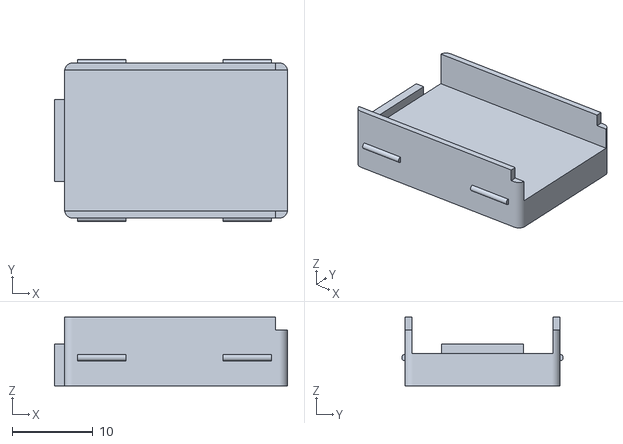
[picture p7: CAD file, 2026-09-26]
cad/desk/v2/k1_deck.stl
28.9 x 20.0 x 8.50

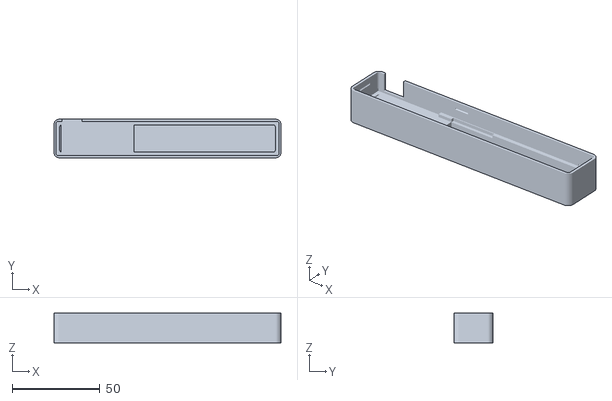
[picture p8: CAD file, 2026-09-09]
cad/v5/k1_tray_mirror.stl
129.0 x 22.0 x 17.0

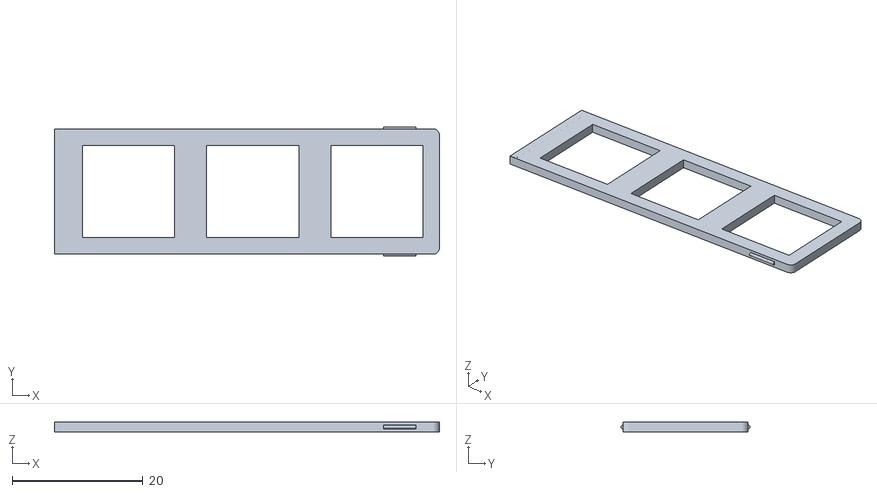
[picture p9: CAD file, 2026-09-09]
cad/desk/v2/k1_plate.stl
59.0 x 19.8 x 1.51

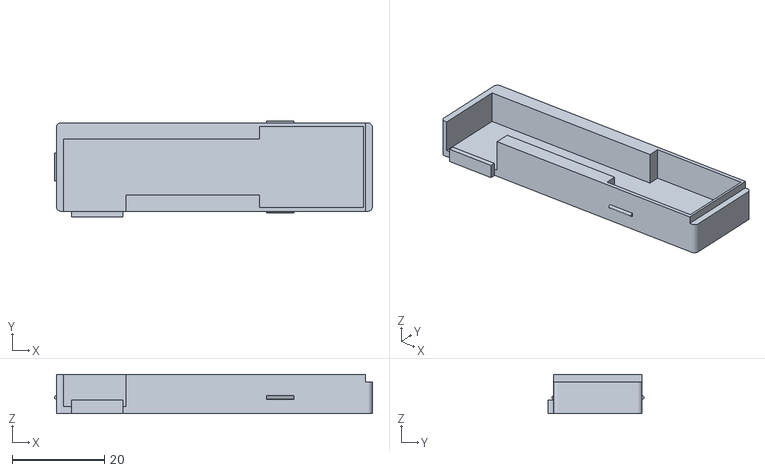
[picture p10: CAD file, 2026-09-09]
cad/v5/k1_deck_mirror.stl
69.0 x 20.9 x 8.50

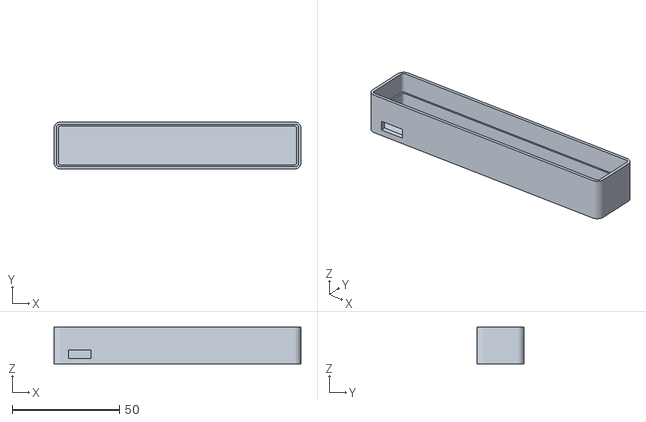
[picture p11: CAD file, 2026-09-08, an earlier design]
cad/k1_tray.stl
115.0 x 22.0 x 17.0

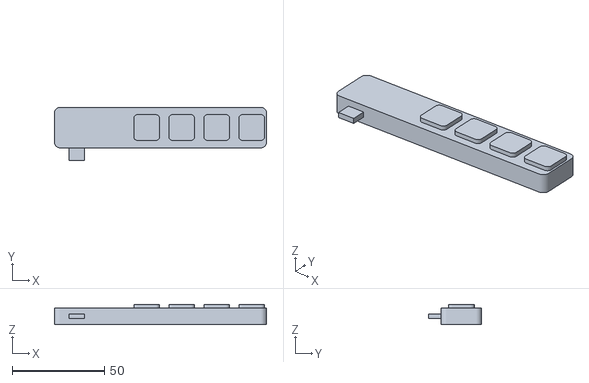
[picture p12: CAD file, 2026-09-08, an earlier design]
cad/v0/k1_v0.stl
115.0 x 29.0 x 11.0

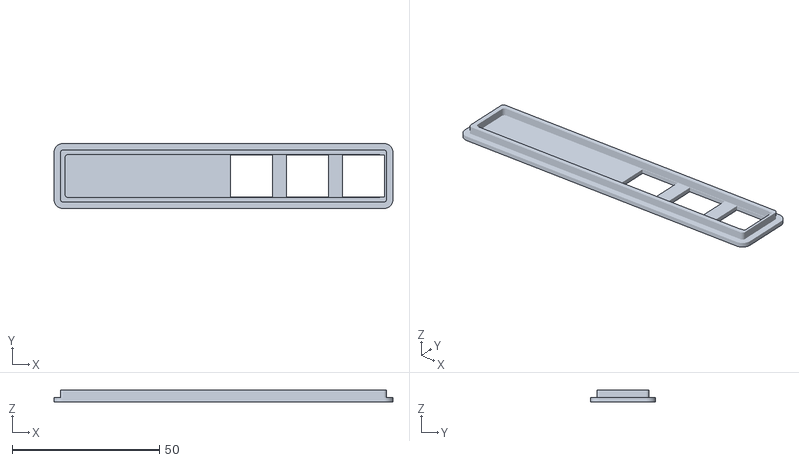
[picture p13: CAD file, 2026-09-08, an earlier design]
cad/v1/k1_lid.stl
115.0 x 22.0 x 4.00

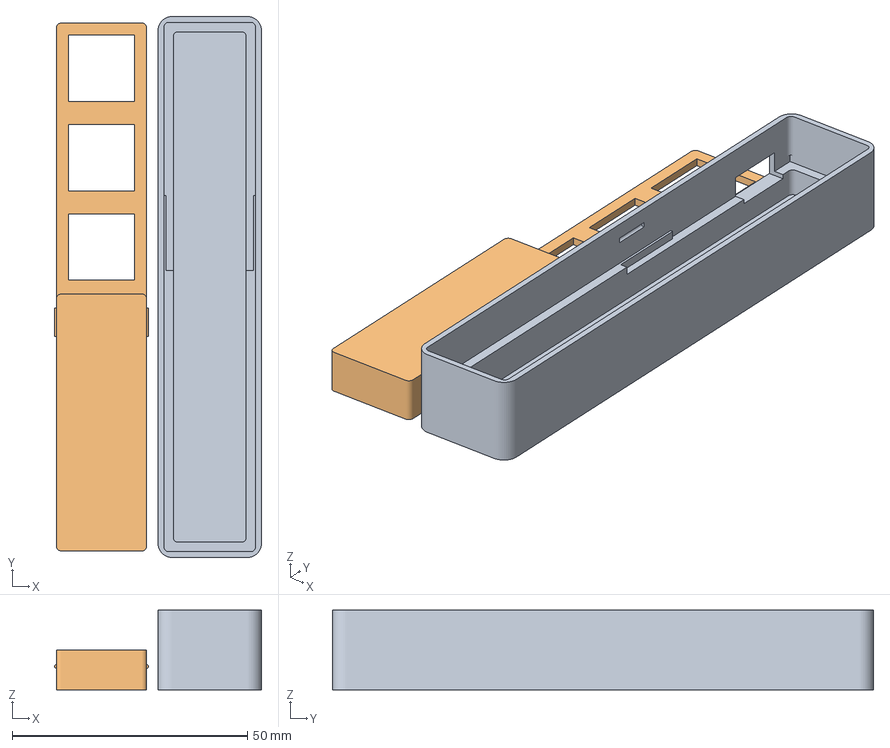
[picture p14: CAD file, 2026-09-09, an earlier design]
cad/v2/k1_v2.3mf
44.0 x 115.0 x 17.0 mm
k1_tray.stl
k1_lid.stl

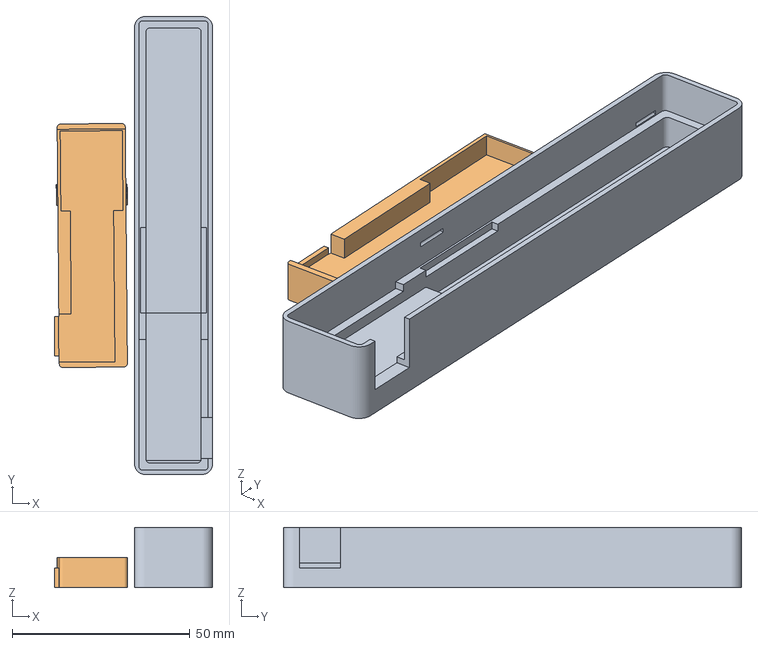
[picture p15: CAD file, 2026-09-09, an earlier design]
cad/v4/k4_v4.3mf
44.6 x 129.0 x 17.0 mm
k1_tray.stl
k1_deck.stl

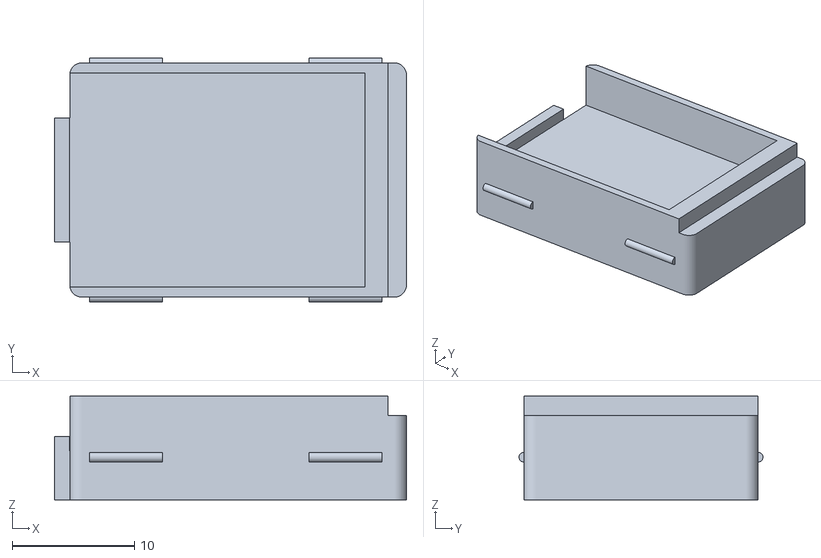
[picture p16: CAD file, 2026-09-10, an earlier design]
cad/desk/v1/k1_deck.stl
28.9 x 20.0 x 8.50

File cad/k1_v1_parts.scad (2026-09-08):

// K1 (Keys v1) — printable 2-part concept, v0.6
// Parts: tray + drop-in lid that doubles as an MX switch plate.
// High-profile: the tray walls continue past the plate, so the lid sits
// recessed on an internal ledge and the switch housings hide in a key well;
// only the caps show. The lid carries a raised deck behind the keys, flush
// with the tray rim. Keycaps are printed separately (Infill Key Caps STLs).
//
// Sized for MX-style clicky switches (PCB/plate mount, through-hole):
//   body 15.6 sq, plate cutout 14.0 sq in a 1.5mm plate (clips grab the
//   plate underside), lower housing ~5mm below plate, upper ~6.6mm above.
// NOTE: clip or bend the switch pins short after soldering — the 7mm cavity
// does not clear full-length 3.3mm pins.
// Body/plug dimensions remain placeholders until the MacBook is measured.
//
// Render one part at a time:
//   openscad -D 'part="tray"' -o k1_tray.stl k1_v1_parts.scad
//   openscad -D 'part="lid"'  -o k1_lid.stl  k1_v1_parts.scad
//   part="assembly" / part="exploded" for viewing (includes mock switches/caps)

part = "exploded"; // tray | lid | assembly | exploded

$fn = 48;

/* ---------- Body ---------- */
body_len  = 115;   // rear (port) to laptop front edge
body_wid  = 22;
body_rad  = 3;

wall       = 2;    // lower walls (electronics cavity)
wall_upper = 1.25; // thinner walls above the ledge -> wider key well
floor_th   = 1.5;
cav_depth  = 7;    // below-plate room: 5 switch + 2 for clipped pins & solder

/* ---------- Lid = switch plate (drop-in) ---------- */
lid_th     = 1.5;  // MX clips are made for a 1.5mm plate — don't change
fit_clr    = 0.15; // per-side clearance, tune per printer
well_depth = 7;    // wall height above the plate; hides the 6.6mm housing

tray_ht = floor_th + cav_depth;               // ledge height, 8.5
body_ht = tray_ht + lid_th + well_depth;      // full shell, 17

/* ---------- Keys (MX) ---------- */
key_count       = 3;
key_pitch       = 19;    // MX standard
keys_from_front = 11;    // first key center from the front end
plate_hole      = 14.1;  // 14.0 nominal + print tolerance
sw_body         = 15.6;  // switch housing (for clearance checks / mock)
sw_upper_ht     = 6.6;   // housing above plate
sw_stem_ht      = 3.6;   // cross stem above housing

/* ---------- Keycap envelope (for mock/clearance only, printed separately) ----------
   Measured from the Infill Key Caps STLs: 18 x 18 x 11.5, hollow skirt,
   cross-socket mouth 1.5 above the skirt edge -> when seated the skirt
   drops ~1mm over the switch housing. */
cap_size    = 18;
cap_ht      = 11.5;
cap_overlap = 1;    // skirt drop below the housing top when seated

/* ---------- USB-C slot (inner wall, near rear) ---------- */
plug_from_rear = 12;   // slot center from rear end
slot_w = 10.5;         // fits a male USB-C breakout plug
slot_h = 4;
slot_z = floor_th + 1; // bottom of slot above cavity floor

/* ---------- Derived ---------- */
cav_len  = body_len - 2 * wall;        // 111
cav_wid  = body_wid - 2 * wall;        // 18
well_len = body_len - 2 * wall_upper;  // 112.5, also the lid seat opening
well_wid = body_wid - 2 * wall_upper;  // 19.5
lid_len  = well_len - 2 * fit_clr;
lid_wid  = well_wid - 2 * fit_clr;

function key_cx(i) = body_len - keys_from_front - i * key_pitch;

/* ---------- Helpers ---------- */
module rounded_box(l, w, h, r) {
    hull()
        for (x = [r, l - r], y = [r, w - r])
            translate([x, y, 0]) cylinder(h = h, r = r);
}

/* ---------- Parts ---------- */
// Frame: X rear->front, Y=0 face touches the laptop, Z up.

module tray() {
    difference() {
        rounded_box(body_len, body_wid, body_ht, body_rad);
        // electronics cavity (lower, 2mm walls)
        translate([wall, wall, floor_th])
            rounded_box(cav_len, cav_wid, tray_ht - floor_th + 0.01, 1);
        // key well + lid seat (upper, thinner walls); the width step at
        // tray_ht forms the ledge the lid rests on
        translate([wall_upper, wall_upper, tray_ht])
            rounded_box(well_len, well_wid, body_ht, 1);
        // USB-C slot through the inner (Y=0) wall
        translate([plug_from_rear - slot_w / 2, -1, slot_z])
            cube([slot_w, wall + 2, slot_h]);
    }
}

// Rear edge of the key well: caps travel freely from here to the front wall;
// behind it the lid deck rises flush with the tray rim.
well_rear = key_cx(key_count - 1) - cap_size / 2 - 1;

// Plate that drops into the well and rests on the ledge, with a raised deck
// over the non-key area so the top surface is flush with the tray rim.
module lid() {
    difference() {
        union() {
            translate([wall_upper + fit_clr, wall_upper + fit_clr, 0]) {
                rounded_box(lid_len, lid_wid, lid_th, 1);
                // deck: fills the well behind the keys, flush with the rim
                rounded_box(well_rear - wall_upper - fit_clr, lid_wid,
                            lid_th + well_depth, 1);
            }
        }
        // MX plate cutouts — switches drop in from the top and clip under
        for (i = [0 : key_count - 1])
            translate([key_cx(i) - plate_hole / 2,
                       (body_wid - plate_hole) / 2,
                       -1])
                cube([plate_hole, plate_hole, lid_th + 2]);
    }
}

// Mock MX switch for assembly views only (not exported)
module switch_mock() {
    color("gray") {
        translate([-sw_body / 2, -sw_body / 2, -5]) cube([sw_body, sw_body, 5]);
        translate([-sw_body / 2, -sw_body / 2, 0])  cube([sw_body, sw_body, sw_upper_ht]);
        translate([-2.05, -2.05, sw_upper_ht])      cube([4.1, 4.1, sw_stem_ht]);
    }
}

/* ---------- Views ---------- */

module assembly(explode = 0) {
    plate_top = tray_ht + lid_th;
    tray();
    translate([0, 0, tray_ht + explode]) lid();
    for (i = [0 : key_count - 1]) {
        translate([key_cx(i), body_wid / 2, plate_top + explode])
            switch_mock();
        // mock keycap (printed separately, seats over the stem)
        color("steelblue")
            translate([key_cx(i) - cap_size / 2, (body_wid - cap_size) / 2,
                       plate_top + sw_upper_ht - cap_overlap + explode * 2])
                rounded_box(cap_size, cap_size, cap_ht, 2);
    }
}

if (part == "tray")          tray();
else if (part == "lid")      lid();
else if (part == "assembly") assembly(0);
else if (part == "exploded") assembly(14);

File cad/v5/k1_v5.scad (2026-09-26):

// K1 enclosure v5 — printable 2-part design
// Parts: tray + drop-in lid that doubles as an MX switch plate.
// High-profile: the tray walls continue past the plate, so the lid sits
// recessed on an internal ledge and the switch housings hide in a key well;
// only the caps show. The lid carries a raised deck behind the keys, flush
// with the tray rim. Keycaps are printed separately (Infill Key Caps STLs).
//
// Sized for MX-style clicky switches (PCB/plate mount, through-hole):
//   body 15.6 sq, plate cutout 14.0 sq in a 1.5mm plate (clips grab the
//   plate underside), lower housing ~5mm below plate, upper ~6.6mm above.
// NOTE: clip or bend the switch pins short after soldering — the 7mm cavity
// does not clear full-length 3.3mm pins.
// Fit dims are tuned empirically against prints: v4 was confirmed on the Mac,
// and v5 raises the USB corridor 2.5mm (chain_raise) to meet the port — check
// the plug height against your Mac before a final print.
//
// Render one part at a time:
//   openscad -D 'part="tray"'  -o k1_tray.stl  k1_v5.scad
//   openscad -D 'part="deck"'  -o k1_deck.stl  k1_v5.scad  (already flipped for printing)
//   openscad -D 'part="plate"' -o k1_plate.stl k1_v5.scad
//   part="assembly" / part="exploded" for viewing (includes mock switches/caps)

part = "exploded"; // tray | lid | assembly | exploded

$fn = 48;

/* ---------- Body ---------- */
body_len  = 129;   // grown for the 44mm USB chain: adapter body starts at
                   // plug_from_rear-6=6, +44 chain, -6.5 insertion -> board
                   // rear face ~43.5, board to ~67, key well from 70
body_wid  = 22;
body_rad  = 3;

wall       = 3.25; // lower walls; with wall_upper this leaves a 2mm ledge
                   // per side, wide enough to carry the board seat

chain_raise = 2.5; // v5: whole USB corridor (cutout, shelf, trench) sits
                   // this much higher so the plug meets the MacBook port
wall_upper = 1.25; // thinner walls above the ledge -> wider key well
floor_th   = 1.5;
cav_depth  = 7;    // below-plate room: 5 switch + 2 for clipped pins & solder

/* ---------- Lid = switch plate (drop-in) ---------- */
lid_th     = 1.5;  // MX clips are made for a 1.5mm plate — don't change
fit_clr    = 0.15; // per-side clearance, tune per printer
well_depth = 7;    // wall height above the plate; hides the 6.6mm housing

tray_ht = floor_th + cav_depth;               // ledge height, 8.5
body_ht = tray_ht + lid_th + well_depth;      // full shell, 17

/* ---------- Lid retention: press-to-open rocker ----------
   Snap bumps only at the FRONT of the deck; the rear (USB end) ledge is
   relieved so the lid can dip there. Press the deck above the USB slot ->
   the lid pivots on the ledge edge at pivot_x -> the front pops up out of
   its grooves. ~0.25mm engagement; walls flex. Tune snap_r/snap_grv_r if
   the lid is too loose or won't click in. */
snap_r     = 0.4;    // bump radius (proud of the lid side face)
snap_grv_r = 0.5;    // groove radius in the tray wall (slop built in)
snap_len   = 6;      // bump length along the body
snap_xs    = [50];   // front of the deck only
pivot_x    = 38;     // ledge support ends here; relieved rearward
relief     = 1.6;    // rear dip travel (drives the front lift)

/* ---------- RP2040-Zero board seat ----------
   The board bridges the cavity, resting its long edges on the widened
   ledges in a shallow pocket (floor level = relieved ledge height, so
   PCB top sits ~0.6 below the lid). A pocket in the deck underside
   clears the top-side USB connector and components. Nominal board
   18 x 23.5 x 1mm PCB — verify with calipers before printing. */
seat_x0     = 45.5;   // rear edge of the seat (board USB-C faces rear);
                      // v3 position +2.5mm toward the keys per the test fit
seat_len    = 24;
seat_wid    = 18.5;
seat_depth  = relief; // shares the relieved-ledge height
comp_pocket = 4.5 + chain_raise; // deck underside pocket over the board —
                      // matches the chain channel depth: one-level hollow

/* ---------- Keys (MX) ---------- */
key_count       = 3;
key_pitch       = 19;    // MX standard
keys_from_front = 11;    // first key center from the front end
plate_hole      = 14.1;  // 14.0 nominal + print tolerance
sw_body         = 15.6;  // switch housing (for clearance checks / mock)
sw_upper_ht     = 6.6;   // housing above plate
sw_stem_ht      = 3.6;   // cross stem above housing

/* ---------- Keycap envelope (for mock/clearance only, printed separately) ----------
   Measured from the Infill Key Caps STLs: 18 x 18 x 11.5, hollow skirt,
   cross-socket mouth 1.5 above the skirt edge -> when seated the skirt
   drops ~1mm over the switch housing. */
cap_size    = 18;
cap_ht      = 11.5;
cap_overlap = 1;    // skirt drop below the housing top when seated

/* ---------- USB-C slot (inner wall, near rear) ---------- */
plug_from_rear = 10.25; // slot center from rear end; rear edge held at
                        // x=4.5 through the fit-test tweaks (now 4.5-16)
slot_w = 11.5;         // sized for the 90-degree adapter's plug base
slot_h = 6;
tab_clr = 0.15;        // clearance around the lid's wall-filler tab
slot_z = (body_ht - slot_h) / 2 + chain_raise; // 8: body center + raise,
                                               // per v4 fit vs the MacBook
                                               // port (slot spans 8-14)
// Lid notch over the slot: the slot's upper half is above the ledge, so the
// lid plate + deck must open up behind it for the plug/adapter to pass.
usb_notch_w     = slot_w + 1;
usb_notch_depth = 12;  // into the lid from the inner edge; placeholder until
                       // the 90-degree adapter is measured (becomes cradle)
usb_notch_h     = slot_z + slot_h + 1 - tray_ht;  // clears the slot top;
                                                  // deck top stays closed
/* Chain channel: hollows the deck underside from the USB notch to the
   board pocket so the adapter + coupler bodies (top ~12.5mm) fit under
   the lid. Height stays just under the tab bottom (4.6 local). */
chain_ch_h    = 4.5 + chain_raise; // trench deepens with the raised chain
chain_ch_wall = 3.5;  // deck wall thickness on both sides of the channel
                      // (the USB notch zone stays open to the inner edge)
deck_rear_wall = 1.5; // deck material kept at its rear end; the hollow now
                      // reaches back this close so the adapter body clears

/* ---------- USB adapter support shelf ----------
   Raised platform on the tray floor the 90-degree adapter's body sits on,
   so its plug lines up with the slot center. Covers the adapter body only —
   the coupler hangs between adapter and board. Measure usb_body_th! */
usb_body_th  = 8;    // est. adapter body thickness
usb_shelf_x0 = plug_from_rear - slot_w / 2 - 0.5;             // 5.5
usb_shelf_len = seat_x0 - (plug_from_rear - slot_w / 2 - 0.5); // to the board seat
usb_shelf_w  = body_wid - 2 * wall;  // full cavity width, wall to wall
usb_shelf_top = slot_z + slot_h / 2 - usb_body_th / 2;        // 4.5

/* ---------- Derived ---------- */
cav_len  = body_len - 2 * wall;        // 111
cav_wid  = body_wid - 2 * wall;        // 18
well_len = body_len - 2 * wall_upper;  // 112.5, also the lid seat opening
well_wid = body_wid - 2 * wall_upper;  // 19.5
lid_len  = well_len - 2 * fit_clr;
lid_wid  = well_wid - 2 * fit_clr;

function key_cx(i) = body_len - keys_from_front - i * key_pitch;

/* ---------- Helpers ---------- */
module rounded_box(l, w, h, r) {
    hull()
        for (x = [r, l - r], y = [r, w - r])
            translate([x, y, 0]) cylinder(h = h, r = r);
}

/* ---------- Parts ---------- */
// Frame: X rear->front, Y=0 face touches the laptop, Z up.
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

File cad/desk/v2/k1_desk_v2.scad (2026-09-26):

// K1 desk variant v2 — printable 2-part design, NO USB adapter chain.
// Derived from cad/v5: same tray + drop-in lid (deck + key plate) and
// press-to-open rocker, but the RP2040-Zero sits hard against the rear
// wall with its own female USB-C facing out a rear port opening — you
// plug a normal USB-C cable straight into the board. The device sits on
// the desk instead of hanging off the MacBook port, so the adapter
// shelf, chain channel, side slot, chain_raise, and the mirrored
// variant are all gone and the body shrinks 129 -> 88.
//
// Sized for MX-style clicky switches (PCB/plate mount, through-hole):
//   body 15.6 sq, plate cutout 14.0 sq in a 1.5mm plate (clips grab the
//   plate underside), lower housing ~5mm below plate, upper ~6.6mm above.
// NOTE: clip or bend the switch pins short after soldering — the 7mm cavity
// does not clear full-length 3.3mm pins.
// Plug engagement depends on how far the board's USB-C face sits behind
// the outer rear face — measure the connector overhang with calipers and
// slide seat_x0 until a cable clicks in fully.
//
// Render one part at a time:
//   openscad -D 'part="tray"'  -o k1_tray.stl  k1_desk_v2.scad
//   openscad -D 'part="deck"'  -o k1_deck.stl  k1_desk_v2.scad  (already flipped for printing)
//   openscad -D 'part="plate"' -o k1_plate.stl k1_desk_v2.scad
//   part="assembly" / part="exploded" for viewing (includes mock switches/caps)

part = "exploded"; // tray | lid | assembly | exploded

$fn = 48;

/* ---------- Body ---------- */
body_len  = 88;    // rear wall + board (to ~25.7) + 3-key well from 29
body_wid  = 22;
body_rad  = 3;

wall       = 3.25; // lower walls; with wall_upper this leaves a 2mm ledge
                   // per side, wide enough to carry the board seat
wall_upper = 1.25; // thinner walls above the ledge -> wider key well
floor_th   = 1.5;
cav_depth  = 7;    // below-plate room: 5 switch + 2 for clipped pins & solder

/* ---------- Lid = switch plate (drop-in) ---------- */
lid_th     = 1.5;  // MX clips are made for a 1.5mm plate — don't change
fit_clr    = 0.15; // per-side clearance, tune per printer
well_depth = 7;    // wall height above the plate; hides the 6.6mm housing

tray_ht = floor_th + cav_depth;               // ledge height, 8.5
body_ht = tray_ht + lid_th + well_depth;      // full shell, 17

/* ---------- Lid retention: press-to-open rocker ----------
   Side snap bumps at the deck's front AND near its rear (the rear pair
   sits on the side walls — the port notch leaves no room on the rear
   face for v5's rear clip); the rear (USB end) ledge is relieved so
   the lid can dip there. Press the deck above the port -> the lid
   pivots on the ledge edge at pivot_x -> the front pops up out of its
   grooves, while the rear bumps ride their grooves' 0.1 radial slop
   (they cam fully out once the freed lid is lifted). ~0.25mm
   engagement; walls flex. Tune snap_r/snap_grv_r if the lid is too
   loose or won't click in. Unlike v5 the board sits IN the dip zone,
   and the deck can only dip ~0.6 before its underside edge strips
   meet the PCB (and the tab the USB shell) — so the pivot sits well
   rearward: lever 1.4-10 vs overhang 10-24 releases the front snaps
   at only ~0.15 rear dip. */
snap_r     = 0.4;    // bump radius (proud of the lid side face)
snap_grv_r = 0.5;    // groove radius in the tray wall (slop built in)
snap_len   = 6;      // bump length along the body
snap_xs    = [6, 24]; // rear pair + front pair, both on the side walls;
                      // the rear pair sits clear of the well's rounded
                      // corners (faces are flat only from x ~2.4)
pivot_x    = 10;     // ledge support ends here; relieved rearward — must
                     // stay rear of the PCB/tab contact points (see above)
relief     = 1.6;    // rear dip travel (drives the front lift)

/* ---------- RP2040-Zero board seat ----------
   The board bridges the cavity, resting its long edges on the widened
   ledges in a shallow pocket (floor level = relieved ledge height, so
   PCB top sits ~0.6 below the lid). A pocket in the deck underside
   clears the top-side USB connector and components. Nominal board
   18 x 23.5 x 1mm PCB — verify with calipers before printing. */
seat_x0     = 1.6;    // rear edge of the seat — the pocket bites into the
                      // rear wall so the USB-C face lands ~1mm behind the
                      // outer face (assumes ~0.8mm connector overhang past
                      // the PCB edge). Slide to tune plug engagement.
seat_len    = 24;
seat_wid    = 18.5;
seat_depth  = relief; // shares the relieved-ledge height
comp_pocket = 4.5;    // deck underside pocket over the board — also the
                      // cable-plug headroom over the connector (top 2.7)

/* ---------- Seat rail relief (v2) ----------
   The rear half of the seat's left rail (y=0 side; rear = USB end) is
   removed down to the cavity floor, so solder joints / wires on that
   board edge clear the holder. The board's left edge is then supported
   by the front half of the rail plus the right rail and pillars. */
rail_cut_len = seat_len / 2;

/* ---------- Board seat pillars ----------
   The board sits loose in its pocket (no retention nubs): the
   connector captured in the port opening limits rear lift to ~0.6
   before its shell meets the tab, the deck hovers 0.6 over the PCB,
   and the rear wall band takes the unplug yank. The pillars continue
   the seat pocket's front wall across the cavity — it otherwise
   exists only on the 1.5mm side ledges — so plug insertion thrust
   bears on full-height posts instead of two thin strips. */
pillar_len = 2.5;
pillar_ys  = [4, body_wid - 4]; // near the pocket's front corners

/* ---------- Keys (MX) ---------- */
key_count       = 3;
key_pitch       = 19;    // MX standard
keys_from_front = 11;    // first key center from the front end
plate_hole      = 14.1;  // 14.0 nominal + print tolerance
sw_body         = 15.6;  // switch housing (for clearance checks / mock)
sw_upper_ht     = 6.6;   // housing above plate
sw_stem_ht      = 3.6;   // cross stem above housing

/* ---------- Keycap envelope (for mock/clearance only, printed separately) ----------
   Measured from the Infill Key Caps STLs: 18 x 18 x 11.5, hollow skirt,
   cross-socket mouth 1.5 above the skirt edge -> when seated the skirt
   drops ~1mm over the switch housing. */
cap_size    = 18;
cap_ht      = 11.5;
cap_overlap = 1;    // skirt drop below the housing top when seated

/* ---------- USB-C port opening (rear end wall) ----------
   The board's own receptacle (8.94 x 3.26 on the PCB top, mouth center
   z ~9.5) shows through the rear wall. The board drops in from the top
   with the connector overlapping the wall, so the wall gets a top-open
   notch and the deck's rear tab fills it back down to the port opening.
   Only the cable's plug shell passes the wall; the overmold butts the
   outer face. */
usb_w   = 10.5;  // opening width, centered on the body
usb_z   = 7.2;   // opening bottom (receptacle bottom 7.9 - clearance)
usb_h   = 4.6;   // opening height when closed (tab bottom at 11.8)
tab_clr = 0.15;  // clearance around the lid's wall-filler tab

/* ---------- Derived ---------- */
cav_len  = body_len - 2 * wall;        // 81.5
cav_wid  = body_wid - 2 * wall;        // 15.5
well_len = body_len - 2 * wall_upper;  // 85.5, also the lid seat opening
well_wid = body_wid - 2 * wall_upper;  // 19.5
lid_len  = well_len - 2 * fit_clr;
lid_wid  = well_wid - 2 * fit_clr;

function key_cx(i) = body_len - keys_from_front - i * key_pitch;

/* ---------- Helpers ---------- */
module rounded_box(l, w, h, r) {
    hull()
        for (x = [r, l - r], y = [r, w - r])
            translate([x, y, 0]) cylinder(h = h, r = r);
}

/* ---------- Parts ---------- */
// Frame: X rear->front, Y centered on the port, Z up.
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

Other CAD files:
cad/v5/k1_plate_mirror.stl
cad/v5/k1_deck.stl
cad/v5/k1_tray.stl
cad/v5/k1_plate.stl
cad/desk/v1/k1_tray.stl
cad/v3/k1_tray.stl
cad/k1_v1.scad
cad/desk/v1/k1_desk_v1.scad
cad/v0/k1_v0.scad
cad/v1/K1v1.3mf
cad/v1/k1_tray.stl
cad/v1/k1_v1.scad
cad/v2/k1_lid.stl
cad/v2/k1_tray.stl
cad/v2/k1_v2.scad
cad/v3/k1_lid.stl
cad/v3/k1_v3.scad
cad/v4/k1_deck.stl
cad/v4/k1_plate.stl
cad/v4/k1_tray.3mf
cad/v4/k1_tray.stl
cad/v4/k1_v4.scad

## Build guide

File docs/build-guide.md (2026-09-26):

# Build guide

This guide takes you from parts to a working Magic Macropad: print the
enclosure, flash the board, wire three switches, put it together, and install
the Mac app. Most of the time is print time. The soldering is six short wires.

1. [Choose a variant](#1-choose-a-variant)
2. [Gather parts and tools](#2-gather-parts-and-tools)
3. [Print the enclosure](#3-print-the-enclosure)
4. [Flash the firmware](#4-flash-the-firmware)
5. [Install the app](#5-install-the-app)
6. [Wire and test the switches](#6-wire-and-test-the-switches)
7. [Assemble](#7-assemble)
8. [Troubleshooting](#8-troubleshooting)
9. [Changing the enclosure](#9-changing-the-enclosure)

## 1. Choose a variant

| | Side-mount | Desk |
|---|---|---|
| Files | [`cad/v5/`](../cad/v5/) | [`cad/desk/v2/`](../cad/desk/v2/) |
| How it connects | Plugs straight into a MacBook's USB-C port and sits flush along its side | Sits on the desk, with a normal USB-C cable at the back |
| Extra parts | A 90° USB-C adapter and a USB-C coupler | None |
| Status | An earlier revision (v4) was confirmed to fit; v5 raises the plug 2.5 mm to meet the port. Check the plug height against your Mac before a final print. | Not test-printed yet, so expect to tune it (see [Troubleshooting](#8-troubleshooting)) |

The side-mount version comes in two mirror-image sets. With the pad running
from the port toward the front of the Mac, keys up:

- The standard files (`k1_tray.stl`, `k1_deck.stl`) fit a USB-C port on the
  Mac's **right** side.
- The `_mirror` files fit the **left** side, which is the only side with USB-C
  on a MacBook Air.
- The key plate is symmetric, so `k1_plate.stl` works for either.

Either way, the USB opening in the tray's side wall must face the Mac.

## 2. Gather parts and tools

**Parts**

| Qty | Part | Notes |
|---|---|---|
| 1 | RP2040-Zero | Waveshare's board, or a pin-compatible clone |
| 3 | MX-style switches | Plate-mount, through-hole. Any feel you like. |
| 3 | MX keycaps | Standard 1u (18 mm wide). Any MX keycap model you print, or off-the-shelf caps. |
| ~30 cm | Thin hookup wire | 28–30 AWG fits the shallow cavity best |
| 1 | USB-C **data** cable | Both variants: for flashing and testing, and it's the desk version's cable. A charge-only cable won't work. |
| 1 | 90° USB-C adapter, female to male, **left/right-angle** | Side-mount only. Plugged into the Mac, its socket must face along the Mac's side, not up or down. Its plug base has to fit an 11.5 × 6 mm opening. |
| 1 | Straight USB-C male-to-male coupler | Side-mount only. With the coupler plugged into the adapter, measure from the back of the adapter's body to the tip of the coupler's free plug: the enclosure expects about 44 mm. |

USB-C adapters vary. If yours don't match, see
[Changing the enclosure](#9-changing-the-enclosure).

**Tools:** a 3D printer, a soldering iron and solder, flush cutters, and wire
strippers. For the software you need a Mac with [Homebrew](https://brew.sh)
and Xcode 26, which needs macOS 15.6 or later; the app itself runs on
macOS 15 or later. [OpenSCAD](https://openscad.org) is only needed if you
change the enclosure.

## 3. Print the enclosure

Exploded view of the side-mount enclosure: the tray at the bottom, the deck and key plate above it, then the switches and keycaps

**The parts, and the words this guide uses for them**

- The **tray** is the base.
- The **lid** comes in two pieces:
  - the **deck**, the long raised cover at the USB end
  - the **key plate**, the flat plate the switches clip into
- **Rear** means the USB end, and **front** means the key end.
- Inside the tray:
  - the lid rests on a **ledge**
  - the board sits in a shallow **pocket** in that ledge
- Side-mount only:
  - the adapter's body sits on a raised **shelf** between the pocket and the
    rear wall
  - its plug leaves through a **notch** in the side wall, which a **tab** on
    the deck closes

Print three parts in PLA:

| Part | Side-mount (`cad/v5/`) | Desk (`cad/desk/v2/`) |
|---|---|---|
| Tray | `k1_tray.stl` (right) or `k1_tray_mirror.stl` (left) | `k1_tray.stl` |
| Deck | `k1_deck.stl` (right) or `k1_deck_mirror.stl` (left) | `k1_deck.stl` |
| Key plate | `k1_plate.stl` | `k1_plate.stl` |

- **Orientation:** print the STLs as they come. The deck is already flipped
  upside down so it needs no supports.
- **Settings used for the prototype:** Bambu Lab A1, 0.4 mm nozzle, 0.20 mm
  layers, 2 walls, 15% infill, no supports, auto brim.
- **Bambu Studio:** [`cad/v5/k1_v5_m.3mf`](../cad/v5/k1_v5_m.3mf) is a
  ready-made project with the left-side (mirror) set.

The fit clearances were tuned on that printer. If your lid comes out too
tight or too loose, see [Troubleshooting](#8-troubleshooting).

## 4. Flash the firmware

Flash the board before you solder anything, so you know it works.

**Get the firmware.** Download the `.uf2` file from the latest release on the
[Releases page](https://github.com/Magic-Technologies-Inc/magic-macropad/releases).
You only need to build it yourself if you change the firmware; see
[Building the firmware yourself](#building-the-firmware-yourself) below.

**Flash.**

1. Hold the **BOOT** button on the RP2040-Zero while you plug it into the Mac
   with the data cable. It shows up as a drive called `RPI-RP2`.
2. Copy the `.uf2` file onto that drive. The board reboots into the firmware
   and the drive disappears.

To check it worked, this should print a line for the board:

```bash
ioreg -p IOUSB -l -w0 | grep -i "Magic Macropad"
```

### Building the firmware yourself

**Install the toolchain (once).** You need CMake, Ninja, picotool, the Pico SDK
with its TinyUSB submodule, and Arm's compiler:

```bash
brew install cmake ninja picotool
git clone --branch 2.1.1 https://github.com/raspberrypi/pico-sdk.git ~/pico-sdk
git -C ~/pico-sdk submodule update --init lib/tinyusb
```

Then download the Arm GNU Toolchain from
[Arm's downloads page](https://developer.arm.com/downloads/-/arm-gnu-toolchain-downloads).
Pick the macOS `.tar.xz` for the **AArch32 bare-metal target
(`arm-none-eabi`)**: `darwin-arm64` for Apple silicon, `darwin-x86_64` for
Intel. Unpack it:

```bash
mkdir -p ~/toolchains
tar -xf ~/Downloads/arm-gnu-toolchain-*-arm-none-eabi.tar.xz -C ~/toolchains
```

Homebrew's `arm-none-eabi-gcc` won't work, because it ships without newlib.

> Prefer a guided setup? The official **Raspberry Pi Pico** extension for
> VS Code installs the SDK and toolchain under `~/.pico-sdk`. Point the two
> variables below at those folders instead.

**Build.** From the repo root, pointing `PICO_TOOLCHAIN_PATH` at the folder
you unpacked:

```bash
cd firmware
export PICO_SDK_PATH=~/pico-sdk
export PICO_TOOLCHAIN_PATH=~/toolchains/arm-gnu-toolchain-14.2.rel1-darwin-arm64-arm-none-eabi
cmake -B build -G Ninja -DCMAKE_BUILD_TYPE=Release
ninja -C build
```

That produces `firmware/build/k1_firmware.uf2`; flash it the same way.

## 5. Install the app

From the repo root:

```bash
brew install xcodegen
cd mac
xcodegen generate
xcodebuild -project MagicKeys.xcodeproj -scheme MagicKeys -configuration Release -derivedDataPath DerivedData build
cp -R "DerivedData/Build/Products/Release/Magic Macropad.app" /Applications/
open "/Applications/Magic Macropad.app"
```

- **Signing:** you don't need an Apple developer account. The app is signed
  for your Mac only.
- **Updating later:** quit the app and delete the old copy from
  `/Applications` before copying the new one in.
- **Just trying it:** after `xcodegen generate`, open `MagicKeys.xcodeproj` in
  Xcode and press ⌘R.

**First launch.** The app has no window and no Dock icon; it lives in the menu
bar.

1. Find its icon: three stacked keys in a rounded outline. The keys fill in
   while the pad is connected. On a MacBook with a notch, a crowded menu bar
   can hide the icon behind the notch.
2. Click the icon to open the panel.
3. Click **Permissions** at the panel's top right. It closes and reopens
   System Settings on the Accessibility page. Turn on Magic Macropad there: the
   app needs that to send keystrokes, media keys, and pastes. Allow
   notifications too, so failed actions can tell you why.
4. Optional: tick **Launch at Login** in the panel's footer.

macOS ties the Accessibility grant to the exact build. After you rebuild the
app, click **Permissions** again: it clears the stale entry and walks you
through turning it back on.

**Out of the box** the keys come with these bindings:

| | Tap | Double tap | Triple tap | Hold |
|---|---|---|---|---|
| Key 1 | Play / Pause | Next Track | Previous Track | Mute |
| Key 2 | Mission Control | Screenshot Region | — | Lock Screen |
| Key 3 | New Claude Chat | New ChatGPT Chat | Improve Writing | Dictation |

**Changing them.** Pick a key on the drawing, click one of its gesture rows,
and choose an action. The chips at the top add per-app profiles: a profile's
bindings apply while that app is in front, and anything it leaves unset falls
back to the default profile. No board yet? The **Test keys** menu in the
footer simulates presses.

## 6. Wire and test the switches

Each switch has two pins. One goes to a GPIO pad on the board and the other to
ground:

```
RP2040-Zero                switches
  GP12 ───────────────── Key 1 ─┐
  GP11 ───────────────── Key 2 ─┤
  GP10 ───────────────── Key 3 ─┤
  GND  ─────────────────────────┘   (daisy-chain the three ground pins)
```

- **No resistors are needed.** The firmware turns on the chip's internal
  pull-ups.
- **Where the pads are:** GP9–GP13 run along the board's short edge opposite
  the USB-C socket, so GP10, GP11, and GP12 are the middle three. GND is on a
  long edge near the socket. Check against your board's pinout diagram.
- **Which switch is which:** Key 1 is the switch nearest the USB end; the app
  draws it at the top, next to the plug. Key 3 is at the front.

**Solder it:**

1. Snap the three switches into the key plate from the top. They click in.
2. Solder a wire from one pin of each switch to its GPIO pad. MX switches
   have no polarity, so either pin works.
3. Solder the switches' other pins together, and to a GND pad.
4. Keep every joint low and let the wires drop into the cavity below the
   board. There's only about 0.6 mm between the board's key end and the key
   plate.
5. Leave enough slack to lift the plate off the tray, but no more. Everything
   has to fold into the 7 mm cavity under the plate.
6. Clip the switch pins short after soldering. Full-length pins don't fit.
7. Route the ground wire for your variant:
   - **Side-mount:** the board's long edges rest on narrow ledges, so plan how
     the ground wire reaches the cavity before you solder it.
   - **Desk:** the rear half of one seat rail is cut away, so solder joints on
     that edge of the board clear it.

**Test before you close it up.** Quit the app first. While it runs, holding a
key fires its Hold action, and Key 2's default Hold locks the screen.

1. Plug the board in and press each switch. The board's LED lights while a key
   is held: **red** for Key 1, **green** for Key 2, **blue** for Key 3. No
   light? Check both wires on that switch.
2. To confirm the order, run the self-test from the repo root and follow its
   prompts:

   ```bash
   cd firmware/tools
   python3 -m venv .venv
   .venv/bin/pip install -r requirements.txt
   .venv/bin/python smoke_test.py
   ```

   It checks that the board answers the app's info request, then asks you to
   press Key 1, Key 2, and Key 3 in turn. It ends with `PASS`, or says what
   went wrong.
3. Keys in the wrong order? Swap the GPIO wires, or just bind the keys in the
   app however they're wired.
4. Open the app again and tap Key 1: by default it plays or pauses music.

## 7. Assemble

**Side-mount**

1. Plug the coupler into the board's USB-C socket, then plug the 90° adapter
   onto the coupler.
2. Lower the board, coupler, and adapter into the tray as one piece. The board
   sits in its pocket with its USB-C socket toward the rear. The adapter's body
   rests on the shelf behind the board, and its plug drops into the notch in
   the side wall.
3. Fold the wires into the cavity and drop the key plate into the front of the
   tray. The end with the two small side bumps goes toward the front. Press
   that end down until the bumps click.
4. Press the deck into the rear of the tray. Its front edge tucks over the key
   plate's rear edge, and its tab fills the top of the notch. Press until it
   clicks.
5. Push the keycaps onto the switches.
6. Plug the pad into your MacBook's port. It rests along the side of the Mac.

**Desk**

1. Put the board's USB-C socket into the opening in the tray's rear wall first,
   then lower the board into its pocket. Nothing clips it in: the rear opening
   and the deck hold it in place.
2. Follow side-mount steps 3–5, then plug in the USB-C cable.

**Opening it again:** unplug it first, from the Mac or the cable, because
pressing the deck pushes its tab down into the USB opening. Then press down on
the deck right above the USB end. The deck rocks on its ledge and its front
pops up. Lift the deck out, then the key plate.

## 8. Troubleshooting

| Problem | What to do |
|---|---|
| The app says "Not connected" | Run the `ioreg` check from step 4. If the board doesn't show up, re-flash it, and make sure the USB chain or cable is fully seated and carries data. |
| The LED lights but actions don't run | Keystroke, media, and paste actions need Accessibility. Click **Permissions** in the panel, and do it again after every rebuild. |
| No LED when pressing a key | Check that switch's two wires: one to its GPIO pad, one to ground. |
| A shell-script action fails | The notification says why. The AI presets need the Claude CLI (`claude`) installed and signed in. Other presets list what they need in their first line. |
| Toggle Dark Mode (or a script that controls another app) does nothing | Allow Magic Macropad under System Settings → Privacy & Security → Automation. |
| The side-mount plug sits too high or low for your Mac's port | The plug's center sits 11 mm above the bottom of the pad. Measure your port's center above the desk and change `chain_raise` by the difference (bigger is higher). Then reprint the tray and deck. |
| The lid won't drop in, or rattles | Change `fit_clr` (clearance per side), then reprint the deck and key plate. |
| The lid won't click in, or pops out | Change the snap bump sizes: `snap_r` and `snap_grv_r` for the deck, `plate_snap_r` and `plate_grv_r` for the key plate. |
| Desk version: the cable doesn't click all the way in | Measure how far the board's USB-C socket sticks out past the PCB's edge, and set `seat_x0` to 0.8 plus that, in mm. Smaller values move the socket toward the outside. Then reprint the tray. |

## 9. Changing the enclosure

The enclosure is parametric OpenSCAD. Each variant's `.scad` file has its
settings near the top, so edit those and re-export the parts you reprint:

```bash
cd cad/v5
openscad -D 'part="tray"' -o k1_tray.stl k1_v5.scad
openscad -D 'part="deck"' -o k1_deck.stl k1_v5.scad
openscad -D 'part="plate"' -o k1_plate.stl k1_v5.scad
```

- **Left-side (mirror) set:** add `-D 'mirrored=true'` and write the
  `_mirror` file names, for example
  `openscad -D 'part="tray"' -D 'mirrored=true' -o k1_tray_mirror.stl k1_v5.scad`.
- **Desk:** the same commands work in `cad/desk/v2/` with `k1_desk_v2.scad`.
- **Different USB parts:**
  - `usb_body_th` sets the shelf height for your adapter's body thickness.
  - A chain shorter or longer than 44 mm moves the board: change `seat_x0` by
    the difference, and `body_len` too if the chain is longer.

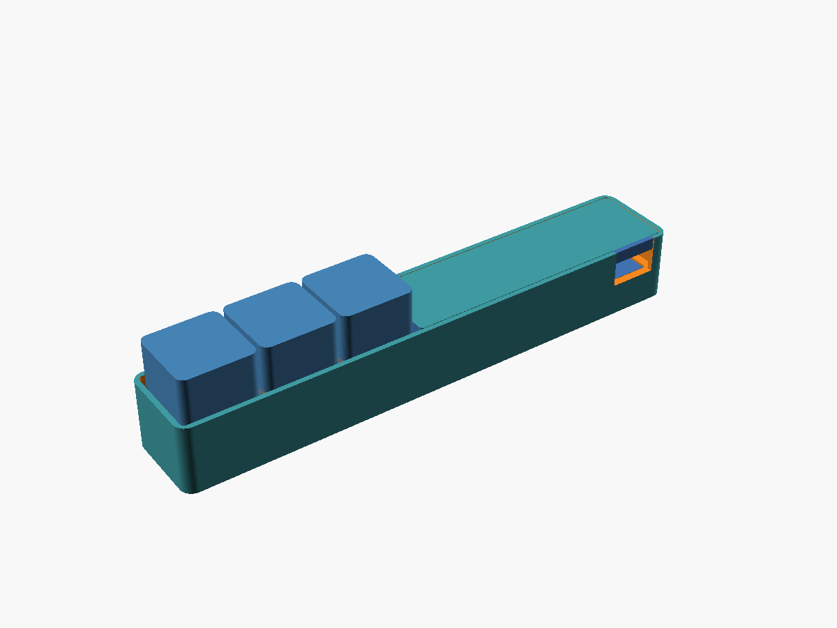
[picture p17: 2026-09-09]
cad/v5/k1_v5_assembled_mirror.png

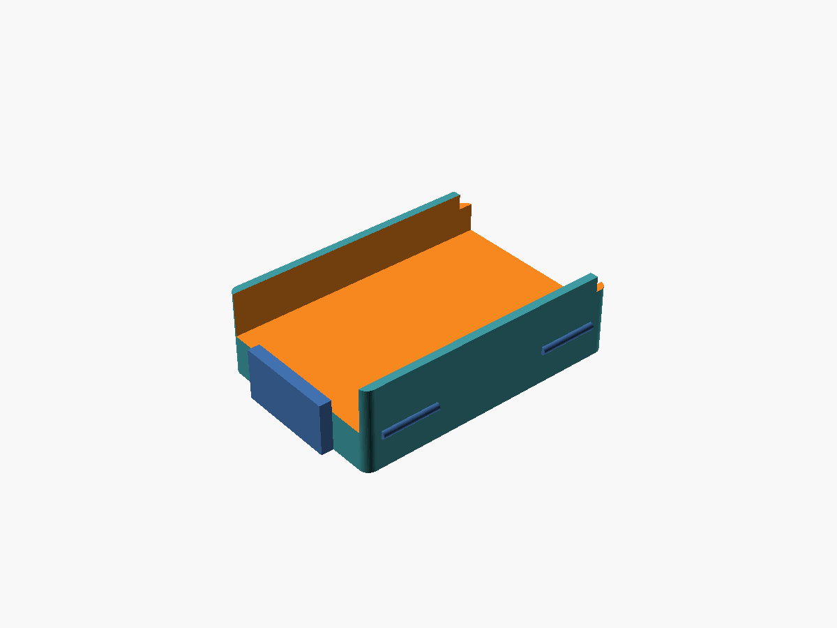
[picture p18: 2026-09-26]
cad/desk/v2/k1_desk_v2_deck_print.png

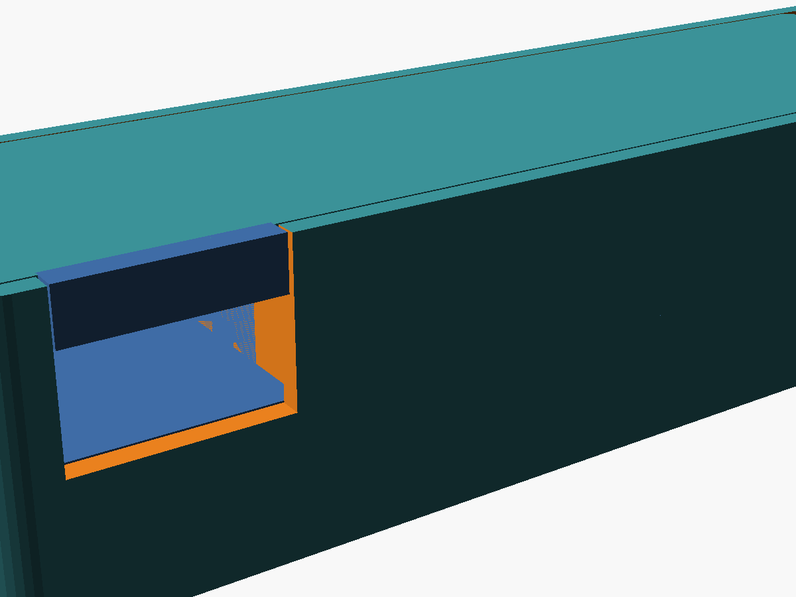
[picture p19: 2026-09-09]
cad/v5/k1_v5_assembled_usb.png

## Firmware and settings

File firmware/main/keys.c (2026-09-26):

#include "keys.h"
#include "protocol.h"
#include "debounce.h"
#include "pico/stdlib.h"
#include <stdio.h>

// Active-low keys, wired key -> GND.
static const uint K1_KEY_GPIOS[K1_KEY_COUNT] = {12, 11, 10};

static queue_t s_event_queue;
static k1_debounce_t s_db[K1_KEY_COUNT];
static uint64_t s_next_scan_us;
static bool s_overflow;  // an edge was dropped because the queue was full

bool k1_keys_pressed(int key)
{
    return s_db[key].stable;
}

bool k1_keys_take_overflow(void)
{
    bool overflow = s_overflow;
    s_overflow = false;
    return overflow;
}

queue_t *k1_keys_init(void)
{
    for (int i = 0; i < K1_KEY_COUNT; i++) {
        gpio_init(K1_KEY_GPIOS[i]);
        gpio_set_dir(K1_KEY_GPIOS[i], GPIO_IN);
        gpio_pull_up(K1_KEY_GPIOS[i]);
        k1_debounce_init(&s_db[i], false);
    }
    queue_init(&s_event_queue, sizeof(k1_key_event_t), 32);
    s_next_scan_us = time_us_64();
    return &s_event_queue;
}

void k1_keys_poll(void)
{
    uint64_t now = time_us_64();
    if (now < s_next_scan_us)
        return;
    s_next_scan_us += 1000;
    if (now > s_next_scan_us + 10000)  // loop stalled; resync instead of bursting
        s_next_scan_us = now;

    for (int i = 0; i < K1_KEY_COUNT; i++) {
        bool pressed = !gpio_get(K1_KEY_GPIOS[i]);  // active low
        if (k1_debounce_update(&s_db[i], pressed)) {
            k1_key_event_t ev = {
                .key = (uint8_t)i,
                .state = s_db[i].stable ? K1_KEY_DOWN : K1_KEY_UP,
            };
            if (!queue_try_add(&s_event_queue, &ev)) {
                s_overflow = true;
                printf("k1_keys: event queue full, dropped key %d\n", i);
            }
        }
    }
}

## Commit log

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2026-09-08 mac: gesture pipeline with deadline timer + DEBUG virtual K1
    - GesturePipeline.swift: Main-actor bound wrapper around GestureEngine with deadline timer
    - AppModel: owns pipeline, resets on K1 disconnect, publishes lastGesture
    - MagicKeysApp: DEBUG menu with virtual K1 tap/double-tap/hold simulation per key
    - All gestures logged to NSLog (ActionEngine wiring in Task 9)
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2026-09-08 mac: redesign as a Logi Options+-style windowed app
    - Regular (Dock) app with a main window opening at launch, menu-bar extra retained
    - Magic brand system ported from iOS: Prussian/Dawn palette + Advercase/Inter fonts
    - K1 drawn as hardware (DeviceView) with the selected key lit in Dawn accent
    - Gesture cards (Tap/Double Tap/Hold) with per-slot action editor popover
    - DEBUG Snapshot hook renders the UI to PNG headlessly for review
2026-09-08 mac: make it a menu-bar app with a popover panel and distinctive K1 icon
    - LSUIElement/accessory app (no Dock); MenuBarExtra with .window popover style
    - Clicking the menu-bar icon drops down the full Magic Keys panel (MenuBarPanel)
    - Custom template menu-bar icon shaped like the K1 (device body + 3 keys),
    replacing the easily-missed circle.grid.3x1 symbol; fills when connected
    - Compact ConfigView + footer (Launch at Login, Quit, DEBUG Virtual K1) sized
    for an 820x560 popover
    - Snapshot hook now renders MenuBarPanel for accurate previews
2026-09-08 mac: fix action configuring — inline editor instead of a nested popover
    The action editor was a .popover presented from inside the MenuBarExtra(.window)
    panel, which is itself a transient NSPopover — presenting a second popover inside
    it dismissed the whole panel, so gestures couldn't be configured. Now the editor
    expands inline within the gesture card (accordion), the bindings pane scrolls, and
    the app activates when the panel opens so the text fields accept keyboard input.
    [k1_lid.stl, k1_tray.stl, k1_v1_parts.scad]
2026-09-08 cad: reorganize into v0/v1/v2, center USB slot as placeholder
    - v0/: original one-piece concept sketch (renamed from k1_v1)
    - v1/: flat 2-part design (v0.4, recovered from 4e5c25b) with its
    slicer project — lid caps the top, switch housings exposed
    - v2/: current design (k1_v2.scad) — recessed key well keeps only the
    caps visible, drop-in lid with raised deck, 7mm cavity (clip switch
    pins), keycap envelope measured from the Infill Key Caps STLs
    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
    [K1v1.3mf, k1_lid.stl, k1_tray.stl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]
2026-09-08 firmware: port from ESP32-S3/ESP-IDF to RP2040-Zero/Pico SDK
    Replaces the ESP-IDF + esp_tinyusb build with a bare-metal Pico SDK
    superloop. Wire protocol, debounce logic, Mac app, and smoke test are
    unchanged. Keys move to GPIO 26/27/28 (active-low, pull-ups). Spec:
    docs/superpowers/specs/2026-09-08-rp2040-port-design.md
    [keys.c]
2026-09-08 mac: match Claude Design + add per-app profiles
    Rebuilds the popover to the Claude Design 'Magic Keys Popover': header with
    status line, per-app profile chips, the K1 drawn as physical keycaps (silver
    caps, warm-accent selected key, USB-C stub), gesture rows with icon/name/hint/
    chevron, a drop-in action picker (list + inline param step), Clear key / Copy to
    all apps, and a footer.
    Per-app profiles (full build):
    - K1Config is now profile-keyed (AppProfile per app + a default), with a Codable
    migration from the legacy flat `keys` array.
    - FrontAppMonitor tracks the frontmost app; gestures resolve against that app's
    profile at press time, so bindings switch by active app.
    - AppModel manag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
2026-09-08 cad: v2 press-to-open lid, USB tunnel through the lid
    - lid tunnel behind the centered USB slot (deck top stays closed) so
    the plug/adapter can pass; placeholder 12mm deep until the 90-degree
    adapter is measured and the cradle lands
    - press-to-open rocker: snap bumps only at the front of the deck
    (grooves in the tray walls at x=50), ledge relieved 1.6mm rear of
    x=38 — pressing the deck above the USB slot pivots the lid and pops
    the front up ~3mm for tool-free removal
    - tray detail render added
    [k1_lid.stl, k1_tray.stl, k1_v2.scad]
2026-09-08 mac: fix action picker sizing — swap into a fixed-height region
    The picker was appended below the card, so the menu-bar popover had to grow to
    show it — but a MenuBarExtra popover is sized when it opens and doesn't reliably
    resize, clipping the picker. Now the card and picker share a fixed-height (290pt)
    region and swap in place, so the picker is always fully visible; its list scrolls
    within the region.
2026-09-08 cad: v2 board seat on widened ledges, 12x5 USB cutout
    - lower walls 2 -> 3.25mm, giving a 2mm ledge per side
    - RP2040-Zero seat: 24 x 18.5mm pocket cut 1.6mm into the ledges at
    x=30-54; the board bridges the cavity, USB-C facing the rear slot,
    and a 3mm pocket in the deck underside clears the connector and
    components (0.4mm margin) while trapping the board when the lid
    snaps in — also resolves the 18mm-board vs 18mm-cavity clash
    - USB slot enlarged to 12 x 5mm (still centered; lid tunnel follows)
    - board mock added to assembly views
    [k1_lid.stl, k1_tray.stl, k1_v2.3mf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]
2026-09-08 mac: record keystrokes instead of typing a raw key code
    The Keystroke action's editor is now a shortcut recorder (KeyRecorderField):
    click to arm, press a key combination, and it captures the key code + modifiers
    via a local key-down monitor (Esc cancels, x clears). Replaces the manual
    key-code field + modifier toggles.
2026-09-08 mac: smooth profile-switch animation
    - Chips animate the active pill expand/collapse (spring) with the name label and
    background crossfading in/out.
    - The gesture column and the context subtitle crossfade when switching profiles
    (keyed to the editing profile id) instead of snapping.
2026-09-08 mac: calmer chip animation
    The spring overshoot and the label's slide-in made chips feel like they flew
    around on selection. Switch to a short (0.16s) ease with an opacity-only label
    transition so the active pill resizes smoothly without bounce or sliding.
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2026-09-08 mac: nicer USB-C plug on the device render
    Replace the flat silver tab with a proper USB-C plug: a metallic connector
    shell (brushed-metal gradient, rim highlight, specular streak, seam line) on a
    short black over-mold neck attaching it to the body.
2026-09-09 cad: v3 — drop-in USB notch with lid tab, sized for the adapter chain
    - new cad/v3/ revision (k1_v3.scad), CLAUDE.md points to it
    - USB cutout 12 x 6mm; the tray wall above it is removed so the
    90-degree adapter drops in from the top, and a filler tab on the lid
    closes the wall back up and captures it (tab stops `relief` above
    the slot so the press-to-open rocker cannot jam on the adapter)
    - lid tunnel starts inside the wall line so it no longer cuts the tab
    - body lengthened 115 -> 129mm for the measured 44mm adapter+coupler
    chain; board seat moved to x=43-67 (chain tip less ~6.5mm insertion),
    key well starts at x=70
    - closed-state renders added (overall + USB face)
    Co-Authored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
    [k1_lid.stl, k1_tray.stl, k1_v2.3mf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]
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2026-09-09 mac: fix ask-clipboard — pass prompt via stdin so allowedTools parses
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2026-09-09 mac: bigger shell-script editor with .sh import; wheel/drag-scroll chips
    Shell Script action:
    - Replace the one-line field with a large multi-line TextEditor (fills the
    picker) so scripts are easy to paste, with a placeholder.
    - Add 'Load .sh file…' to import a script's contents via NSOpenPanel.
    App chips row:
    - Back it with an NSScrollView (ChipsScroller) so every input works: trackpad,
    mouse scroll wheel (vertical wheel maps to horizontal), and click-drag panning.
    Replaces the SwiftUI ScrollView + chip-by-chip drag gesture.
2026-09-09 mac: edit-in-place picker, bigger close target, aligned script editor
    - Tapping a gesture that already has an action opens straight into that action's
    editor (params stage) instead of the action list. Media (no params) still
    shows the list.
    - Enlarge the picker's close (x) and back (chevron) hit targets to 30x30.
    - Replace the shell TextEditor with a controlled NSTextView (ScriptEditor): fixed
    (10,10) text insets so the placeholder aligns with the cursor, and smart
    quote/dash/text substitutions disabled so scripts aren't mangled.
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2026-09-09 mac: triple-tap gesture + picker/header/footer cleanups
    - Gesture engine now detects triple-tap (generalized tap counter, up to 3);
    Gesture/KeyBinding gain tripleTap. Double-tap now waits for a possible third
    tap before firing. 36 core tests pass (added triple-tap coverage).
    - Add a Triple tap row; rows shortened to fit four in the aligned warm panel.
    - Remove the header connection line (kept only the footer's dot); drop firmware
    from the footer.
    - Remove the 'Give an app its own key setup' subtitle.
    - Make the debug key tester an obvious 'Test keys' button (adds Triple tap).
    - Picker: Back now returns home; the X is replaced by a 'Change action' button
    (to the action list); the Remo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
2026-09-09 cad: v4 — split lid (deck + key plate), full-height tab, adapter shelf
    - new cad/v4/ revision (k1_v4.scad); lid now prints as two parts:
    deck (exported pre-flipped, all pockets/tab face up — no supports)
    and a flat key plate. Lock: stepped roof lip on the deck traps the
    plate's rear once the deck snaps in; plate side bumps click into
    wall grooves near the front
    - fix: key plate kept deck-height material at its rear that collided
    with the roof lip — clamped to plate thickness
    - filler tab extended flush with the slot top: closed cutout is
    exactly 12x6mm (open the lid with the adapter unplugged)
    - chain channel hollows the deck underside from the USB notch to the
    board pock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
    [k1_deck.stl, k1_plate.stl, k1_tray.3mf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]
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2026-09-09 cad: v4 fit-test refinements — full shelf, one-level deck hollow, 11mm cutout
    - adapter support shelf extended: full length (USB notch to board seat)
    and full cavity width, top at 4.5mm
    - deck underside hollow is one level: board pocket deepened to match
    the 4.5mm chain channel (connector clearance grows to ~1.9mm)
    - chain channel is now a centered trench with 4mm deck walls on both
    sides; the USB notch zone stays open to the inner edge
    - USB cutout narrowed to 11x6mm: rear edge held at x=6, keys-side
    edge moved 1mm rearward (slot center now 11.5); tab/notch/channel
    follow derived
    [k1_deck.stl, k1_tray.stl, k1_v4.scad]
2026-09-09 cad: v4 — shift USB cutout 1.5mm rearward
    Slot center 11.5 -> 10 (spans x=4.5-15.5); tab, drop-in notch, support
    shelf and channel opening follow derived. Moves the adapter chain away
    from the deck's key end so the lid closes clear of the board. Rear wall
    stub next to the cutout is now ~1.25mm.
    [k1_deck.stl, k1_tray.stl, k1_v4.scad]
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2026-09-09 mac: one-click Permissions button in the header
    Add a Permissions button (top-right) that clears any stale Accessibility grant
    from a previous build (tccutil reset), prompts for Accessibility, opens the
    Accessibility settings pane, and requests Notifications. Shows a green
    checkmark-shield when Accessibility is already trusted.
2026-09-09 mac: quit System Settings before reopening Accessibility pane
    The Permissions button ran `tccutil reset` but the Privacy →
    Accessibility list caches its rows and does not live-refresh, so it
    kept showing a stale "on" toggle for the entry we had just cleared.
    That was misleading: after a reset the running (ad-hoc-signed) build is
    actually untrusted, but the stale "on" made it look already granted, so
    the user never re-enabled it and synthesized media/key events kept
    silently failing.
    Quit System Settings (and its legacy name) before reopening the pane so
    it loads a fresh list reflecting the true state, with a short delay so
    the app fully terminates before relaunch.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
    [k1_deck.stl, k1_v4.scad]
2026-09-09 mac: remove dead space below the keycap + gestures card
    The card/picker region was pinned at 290pt while the main card is only
    254pt tall (222pt holder + 4pt top inset + 14pt padding top & bottom),
    so ~36pt of empty space sat between the card and the footer. Tighten the
    region to 254pt; the picker fills it and scrolls, so it's unaffected.
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2026-09-09 cad: v4 cutout reposition and wider chain trench
    - USB cutout shifted 1.5mm rearward then widened 0.5mm toward the
    keys: now 11.5 x 6mm spanning x=4.5-16 (rear edge held); tab,
    drop-in notch, shelf start, and channel opening all follow derived
    - deck chain-channel walls 4 -> 3.5mm each side (trench 12.2mm wide)
    [k1_deck.stl, k1_tray.stl, k1_v4.scad]
2026-09-09 cad: v5 — USB corridor raised 2.5mm to meet the MacBook port
    - new cad/v5/ revision (k1_v5.scad) from the confirmed-fitting v4
    - single chain_raise=2.5 parameter lifts the whole corridor: cutout
    now spans 8-14mm (tab follows, 3mm tall), adapter shelf top at 7mm,
    deck chain trench and board pocket deepened to 7mm (one level, and
    the raised chain keeps headroom to the board)
    - board seat unchanged (already at the lid plane) — the coupler/board
    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
    [k1_deck.stl, k1_plate.stl, k1_tray.stl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]
2026-09-09 cad: v5 rear clip on the deck
    - third snap bump on the deck's rear end face (same 0.4mm x 6mm as
    the side clips) with a matching groove in the tray's rear wall —
    the rear can no longer lift at the seam
    - press-to-open unaffected: the rocker's ~1.3mm dip cams the bump
    down out of its 0.25mm-engagement groove
    [k1_deck.stl, k1_tray.stl, k1_v5.scad]
2026-09-09 cad: v5 mirrored variant for the MacBook's other side
    - `mirrored` flag in k1_v5.scad wraps the part exports in a Y mirror —
    one source file drives both sides, rear clip included
    - k1_{tray,deck,plate}_mirror.stl exported (tray/deck are chiral and
    need these; the key plate is symmetric so either file works)
    - unmirrored exports verified byte-identical to the printed ones
    [k1_deck_mirror.stl, k1_plate_mirror.stl, k1_tray_mirror.stl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]
2026-09-09 cad: desk variant v1 — adapter-less, board USB-C out the rear
    Derived from v5: drops the whole USB chain (shelf, channel, side slot,
    chain_raise, mirrored variant); the RP2040-Zero seats at the rear wall
    so its own female USB-C shows through a rear port opening (drop-in
    notch + lid tab, v5 pattern rotated to the end wall). Body 129 -> 88.
    Rocker rescaled (pivot 18, snaps at 24); rear clip split into two
    flanking the port. Tune seat_x0 against the real connector overhang.
    [k1_desk_v1.scad]
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2026-09-10 cad: desk v1 board retention nubs
    Cable forces act above the PCB — plugging tilts the board rear-up,
    unplugging front-up — and the deck can't hold it down (the rocker
    dips ~1.3mm over the seat), so the tray pins it: round nubs on the
    seat pocket's rear and front walls overhang the PCB corners 0.25mm,
    undersides 0.1 over the PCB top, trimmed flush above the ledge so
    the seated deck clears. Install rear-first, snap the front edge in.
    The deck's component pocket now opens through its rear face for the
    rear nubs. Deck/tray boolean intersection verified empty.
    [k1_deck.stl, k1_desk_v1.scad, k1_tray.stl]
2026-09-10 cad: desk v1 retention nubs — wedge profile for clean printing
    The round nubs' fit-critical undersides would droop when printed
    upright; the triangular profile keeps both faces at 45 degrees so
    the tray prints them cleanly. The top chamfer also lets the board
    press straight in (both pairs cam as the PCB bows — no rear-first
    tilt), and the opposing 45-degree faces trap it in the seat.
    Deck/tray boolean intersection re-verified empty.
    [k1_desk_v1.scad, k1_tray.stl]
2026-09-10 cad: desk v1 review fixes — nub pillars and rocker pivot
    Pre-print review caught two real faults:
    - The front retention nubs hung over open cavity: the seat pocket's
    front wall only exists on the 1.5mm side ledges, so the nubs were
    unprintable and unanchored, and plug thrust bore on the two ledge
    strips alone. Full-height pillars now continue the wall across the
    cavity behind each nub.
    - Press-to-open couldn't release: the board sits in the dip zone
    (unlike v5), and the deck bottoms on the PCB/USB shell after ~0.6mm
    of dip, while the pivot-18 geometry needed ~1.1mm to pop the front
    snaps. Pivot moved to x=10 so release needs only ~0.15mm of dip.
    Deck/tray boolean intersectio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
    [k1_desk_v1.scad, k1_tray.stl]
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2026-09-10 cad: desk v1 — drop rear board nubs, move rear lid fits to the sides
    The rear retention nubs go: the connector sits captured in the port
    opening (~0.6 lift before its shell meets the tab) and the rear wall
    band takes the unplug yank, so the front nub pair alone pins the
    board. Install is connector-first into the port, then press the
    front edge down past the nubs.
    The rear-face clips move onto the side walls as a second snap_xs
    entry at x=6 — clear of the well's rounded corners (a first try at
    x=5 clashed with the corner bulge) — so the rear face now carries
    only the port tab. During a rocker press the rear bumps ride their
    grooves' radial slop and cam out once the freed lid is lifted.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
    [k1_deck.stl, k1_desk_v1.scad, k1_tray.stl]
2026-09-10 cad: desk v1 — remove the remaining board retention nubs
    The board now sits loose in its pocket: the connector captured in
    the port opening limits rear lift, the deck hovers 0.6 above the
    PCB, and the rear wall band takes the unplug yank. The front-wall
    pillars stay as the bearing for plug insertion thrust.
    [k1_desk_v1.scad, k1_tray.stl]
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2026-09-15 firmware: reverse key order — key 0 is GPIO 12, key 2 is GPIO 10
    [keys.c]
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2026-09-19 mac: add "Switch App" system action for ⌘Tab
    ⌘Tab can't be captured by the keystroke recorder — the WindowServer
    consumes it for the app switcher before the Tab keyDown reaches the app,
    so the local event monitor never sees it. Rather than record it, expose
    it as a named System Action.
    Playback posts a real hold-⌘ / tap-Tab / release-⌘ sequence (the
    switcher only commits when the Command flag drops, so a plain keystroke
    won't work). Gated on Accessibility like other synthesized events.
2026-09-20 mac: warn when recording a reserved system shortcut
    The keystroke recorder silently captured nothing when a user pressed a
    combo macOS reserves (⌘Tab, Spotlight, Mission Control) — the WindowServer
    eats it before the keyDown arrives, and the app just switched away.
    Detect it: track modifier state via a flagsChanged monitor (delivered
    while we're still frontmost) and watch didResignActiveNotification. If the
    app resigns active mid-recording with a modifier held, show a hint
    pointing at the System Action instead. A reference-typed box lets the
    escaping monitors/observer read live state rather than stale @State.
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2026-09-20 mac: add AI actions and seed a useful default profile
    AI action type (the differentiator for an AI-company keypad):
    - New Claude Chat — opens claude.ai/new
    - New ChatGPT Chat — opens the ChatGPT app if installed, else the web
    - Dictation — starts macOS Dictation (posts the F5 dictation key; needs
    Accessibility, and relies on the default F5 dictation shortcut)
    First-run seed: a brand-new install (no config on disk, or a corrupt /
    invalid one) now gets a useful 3-key layout instead of blank keys —
    key 1 media (play/next/prev/mute), key 2 system (Mission Control /
    screenshot / lock), key 3 AI (Claude / ChatGPT / dictate). makeSeeded()
    never overwrites an existing config; makeDefault(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
2026-09-20 mac: add Open File / Folder action
    New ActionConfig.openPath opens a specific file or folder via NSWorkspace
    (expands ~, warns if the path no longer exists). Picked from the editor
    with a file/folder panel that commits on selection, like Open App. The
    gesture row shows the item's name. Additive Codable case; round-trip
    tested.
2026-09-23 mac: expand shell-script examples into categorized presets
    Grow the Examples menu into an AI-user-focused preset library, grouped
    into category submenus (AI · Clipboard, AI · Coding, Git, Editor &
    Finder, System):
    - AI · Clipboard: pipe the clipboard through `claude -p` and put the
    result back (Improve Writing, Explain Clipboard, Summarize, Explain
    This Error).
    - AI · Coding: New Claude Session Here (Terminal at the Finder folder),
    AI Commit (message generated from the staged diff).
    - Git: Copy Diff, Commit & Push, Open Repo on GitHub, Copy Branch Name.
    - Editor & Finder: Open the Finder folder in Cursor.
    - System: the prior toggles/utilities.
    ScriptPreset gains a category; the p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
2026-09-23 mac: seed "Improve Writing" on the AI key's triple tap
    Fresh installs now get the clipboard "Improve Writing" shell preset on
    key 3 triple tap, alongside the AI chat/dictation bindings — showcasing
    the claude -p pipeline out of the box.
2026-09-26 cad: desk v2 — wire clearance past the board seat
    - remove the rear half of the seat's left rail down to the cavity floor
    so solder joints / wires on that board edge clear the holder
    - run the deck's board pocket out the front face (board-window width)
    so top-side wires can pass forward; the roof lip still traps the
    plate at the sides
    - CLAUDE.md: desk/ layout now points at v2 as current
    [k1_deck.stl, k1_desk_v2.scad, k1_plate.stl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]
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2026-09-26 mac: fix review findings in the app
    - Keep Awake holds a ProcessInfo activity instead of an unmanaged caffeinate,
    so quitting or crashing can't leave the Mac unable to sleep
    - System actions report non-zero exits, Open URL / Open File report
    failures, and the app declares NSAppleEventsUsageDescription so Apple
    Events can prompt instead of being denied
    - Keystrokes and Paste Text step aside when the panel is frontmost and post
    once the app the gesture resolved for is active again
    - HID input and gesture deadlines run in common run-loop modes, so menus and
    modal panels no longer stall them
    - HIDService also matches usage page 0xFF60 (1209:0001 is a shared test ID),
    listens to one p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
2026-09-26 docs: credit vendored BSD-3 code; fix stale claims
    - ws2812.pio gets its upstream copyright and SPDX header back; it and
    pico_sdk_import.cmake are listed in THIRD_PARTY_NOTICES with the BSD-3
    text, and the README's license exceptions mention them
    - CLAUDE.md: ActionEngine is an exhaustive switch over ActionConfig (there
    is no MagicAction protocol), and the Mac project is XcodeGen-generated
    - PROJECT_SUMMARY: smart-home actions would be a new ActionConfig case
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2026-09-26 firmware: smoke test asks for Key 1-3 and checks the order
    "Left to right" meant nothing on a pad that runs along a Mac, and the test
    passed on any six well-formed events. It now asks for Key 1, Key 2, then
    Key 3, prints keys the way the app numbers them, and fails with a hint if
    they arrive in a different order.
    [smoke_test.py]
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
